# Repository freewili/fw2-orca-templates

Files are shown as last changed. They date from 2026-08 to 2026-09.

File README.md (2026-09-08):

# fw2-orca-templates

Example project templates for the FreeWili 2 ORCA module.

Currently supports:

- [KiCad](./kicad) — schematic/PCB template (`ORCATemplate`)
- [Connector pinouts](./PINOUTS.md) — Free Wili OG and Free Wili 2 20-position and 10-position connector pin tables
- [ORCA_NRF example](./examples/ORCA_NRF) — example ORCA module board carrying an NRF24L01 radio
- [GPIO Joiner example](./examples/gpiojoiner) — a routed KiCad 10 star board for testing a pair of FreeWili 2 / OG devices, with fabrication and assembly files

## KiCad template

The `kicad/` directory contains a starter KiCad 7 project (`ORCATemplate`) for
building ORCA module boards, including a 3D `.step` model and a custom
`EEPROM.pretty` footprint library.

The ORCA module connects via two headers, `CN1` and `CN2`:

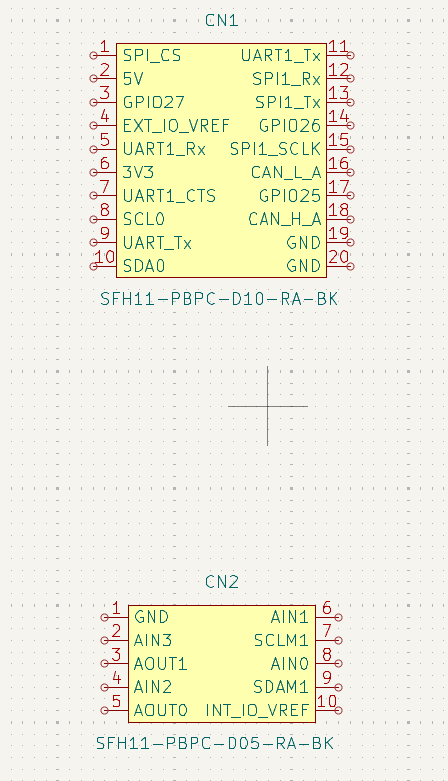
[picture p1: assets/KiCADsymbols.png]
ORCA connector symbols


> **Note:** `kicad/fp-lib-table` currently references footprint libraries
> (`IDC_10`, `IDC_20`) by absolute path on another machine. Update these
> library paths (or replace them with the project-relative `${KIPRJMOD}`
> style used for `EEPROM`) before relying on the template on a fresh
> checkout.

## ORCA_NRF example

The `examples/ORCA_NRF/` directory contains a complete example ORCA module
project built from the template: an NRF24L01 radio carrier with the `CN1`
(20-pin) and `CN2` (10-pin) headers and the ID EEPROM.

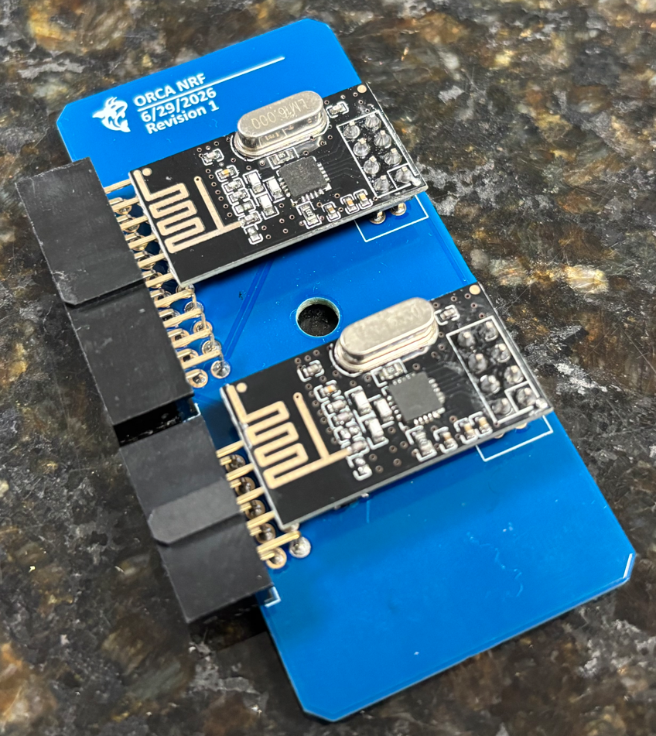
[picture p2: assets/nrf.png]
Assembled ORCA NRF example board with two NRF radio modules


User-provided photograph of the assembled ORCA NRF board.

> **Note:** The symbols and footprints are embedded in the schematic and PCB,
> so the project opens without extra libraries. The 3D model references in
> `ORCA_NRF.kicad_pcb` use absolute paths from another machine and will show
> as missing in the 3D viewer until you repoint them.

## GPIO Joiner example

[GPIO Joiner rev A](./examples/gpiojoiner) provides two opposing FreeWili 2
positions and two opposing OG positions. Connect one device per electrical
side, two devices total. A 24LC02BT ORCA EEPROM connects to shared FW2 I2C1.

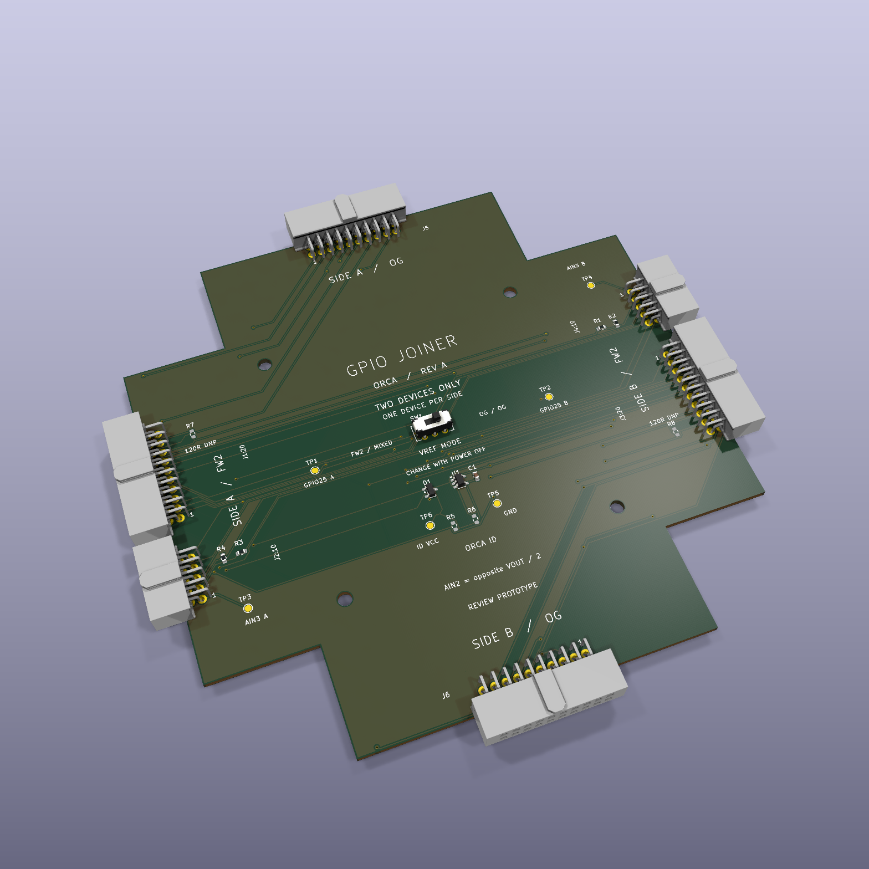
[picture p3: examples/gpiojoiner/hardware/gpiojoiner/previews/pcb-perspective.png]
GPIO Joiner rev A angled KiCad board preview


The example includes editable KiCad sources, project-local symbols,
footprints and 3D models, top/bottom board images, a schematic PDF, and
[prototype manufacturing files](./examples/gpiojoiner/hardware/gpiojoiner/manufacturing/revA).
The [PCBWay quote-form answers](./examples/gpiojoiner/hardware/gpiojoiner/manufacturing/PCBWAY-QUOTE-ANSWERS.md)
show how to request five fully assembled prototypes.

This is an unbuilt prototype: physical mating, EEPROM ID programming and
bench operation remain to be validated. Optional R5-R8 models appear in the
preview but are DNP in the assembly BOM. See the example README for operating
limits and verification evidence.

Repository agent workflow is documented in [AGENTS.md](./AGENTS.md).

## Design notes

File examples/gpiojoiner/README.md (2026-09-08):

# FreeWili GPIO Joiner

KiCad project for a four-arm star test board with FW2 connectors opposite
each other and OG connectors on the perpendicular axis. Rev A supports
**two connected devices, one on Side A and one on Side B**, using either
generation on each side.

GPIO Joiner rev A angled board preview

KiCad 3D preview of the routed prototype. Connector models show the board
layout; full device cases and physical mating have not been verified.
Optional R5-R8 models appear in these views but are DNP in the assembly BOM.

Open [gpiojoiner.kicad_pro](hardware/gpiojoiner/gpiojoiner.kicad_pro).
See the [board preview](hardware/gpiojoiner/previews/pcb-top.png),
[schematic PDF](hardware/gpiojoiner/previews/schematic.pdf), and
[setup instructions and BOM](hardware/gpiojoiner/README.md).

The required 24LC02BT ORCA EEPROM is connected to shared FW2 I2C1. VREF
mode is selected with a labeled switch. Programmable-output measurements
use 2:1 dividers, so test firmware must multiply the opposite AIN2 reading
by two. The original wiring authority remains [gpiojoiner spec.md](gpiojoiner%20spec.md).

Prototype manufacturing files for JLCPCB and PCBWay are prepared:
[Gerber ZIP](hardware/gpiojoiner/manufacturing/revA/gpiojoiner-revA-gerbers.zip),
[assembly package](hardware/gpiojoiner/manufacturing/revA/gpiojoiner-revA-assembly.zip),
and [order settings / fit check](hardware/gpiojoiner/manufacturing/revA/README.md).
The working quote is five fully assembled boards; no order has been placed.

This is a routed prototype. CAD verification is recorded in
[reports/verification.md](hardware/gpiojoiner/reports/verification.md).
Check actual device mating and supplier assembly previews before ordering.
EEPROM identification and bench validation remain required before production
release. Four simultaneously attached devices are unsupported by this revision.

| Top view | Bottom view |
| --- | --- |
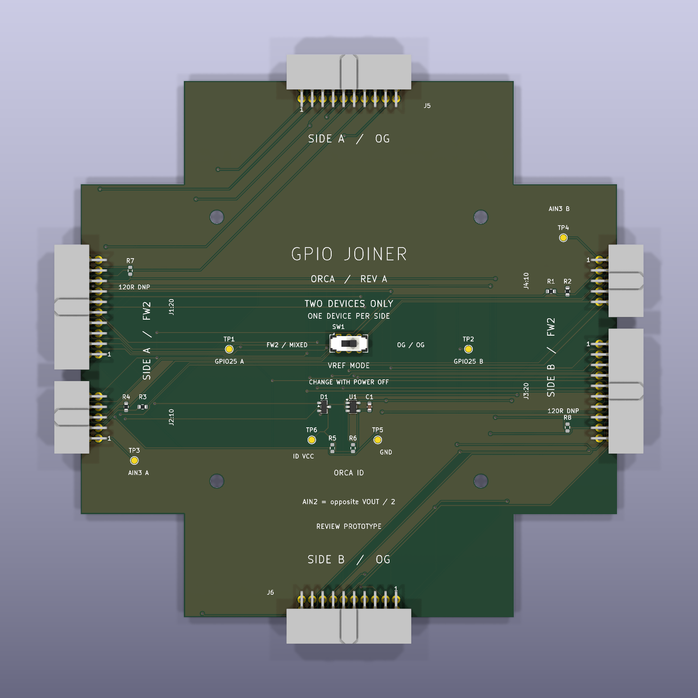
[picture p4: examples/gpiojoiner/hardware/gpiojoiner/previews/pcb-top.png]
Top of GPIO Joiner rev A
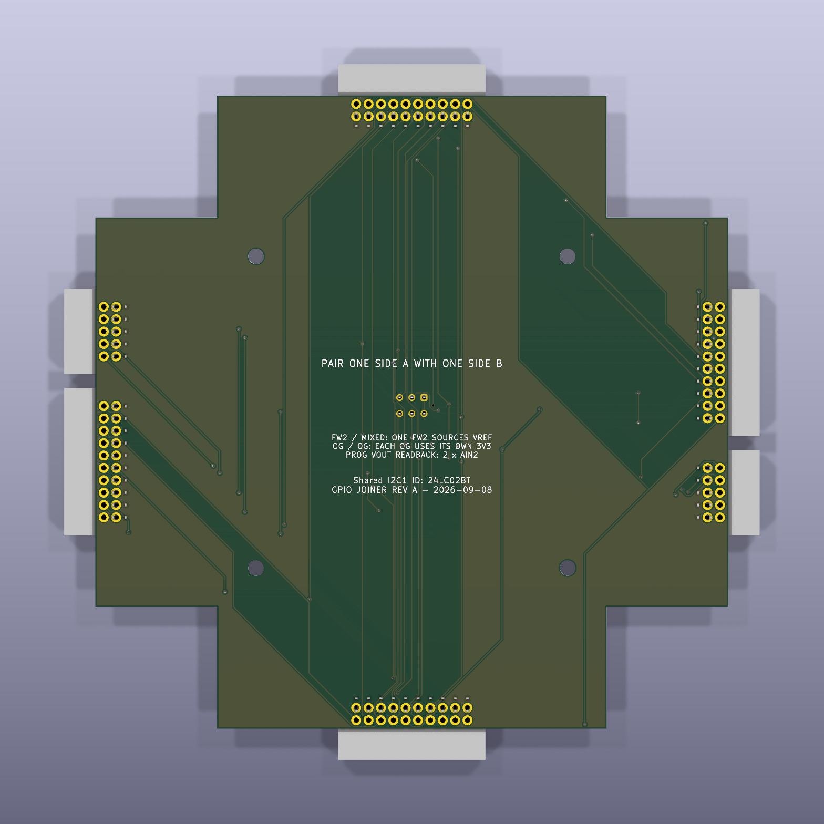
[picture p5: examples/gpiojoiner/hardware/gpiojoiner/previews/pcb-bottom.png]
Bottom of GPIO Joiner rev A
|  |  |

The [PCBWay quote-form answers](hardware/gpiojoiner/manufacturing/PCBWAY-QUOTE-ANSWERS.md)
provide a field-by-field example for requesting a fully assembled prototype.
Agent workflow and board requirements are recorded in [AGENTS.md](AGENTS.md).

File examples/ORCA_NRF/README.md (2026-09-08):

# ORCA NRF example

NRF radio carrier example for FreeWili 2.

Assembled ORCA NRF example board

Open [ORCA_NRF.kicad_pro](ORCA_NRF.kicad_pro) in KiCad to inspect the
[schematic](ORCA_NRF.kicad_sch) and [PCB](ORCA_NRF.kicad_pcb).

The photograph shows the assembled example board. The existing PCB's 3D
model references include absolute paths; see the [repository notes](../../README.md#orca_nrf-example)
when opening its 3D view on another machine.

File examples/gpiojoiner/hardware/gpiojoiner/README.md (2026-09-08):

# GPIO Joiner - rev A review prototype

Open **gpiojoiner.kicad_pro** in KiCad 10 or newer. The schematic, PCB,
symbol library, footprints, and 3D models are included in this folder.
See [schematic PDF](previews/schematic.pdf), [board preview](previews/pcb-top.png),
[design details](DESIGN.md), and [BOM](BOM.md).

[Prototype manufacturing package and order settings](manufacturing/revA/README.md)
are prepared for JLCPCB and PCBWay, including Gerbers, exact-part BOMs,
supplier placement CSVs, and a 1:1 fit/assembly PDF. The working quantity is
five fully assembled boards. No supplier order or live quote has been submitted.

Angled KiCad preview of GPIO Joiner rev A

| Top view | Bottom view |
| --- | --- |
| Top of the GPIO Joiner PCB | Bottom of the GPIO Joiner PCB |

These are CAD previews; full device enclosures and physical mating are not
verified. Optional R5-R8 models appear in the views but are DNP in the
prototype assembly BOM.

This revision implements the test cable described in the root
`gpiojoiner spec.md`. It has four docking positions in a star, intended
for **two attached devices: one on Side A and one on Side B**.

```text
                         OG A - J5
                            |
 FW2 A - J1 + J2 -------- JOINER -------- J3 + J4 - FW2 B
                            |
                         OG B - J6
```

| Test pair | Side A | Side B | SW1 position |
| --- | --- | --- | --- |
| FW2 / FW2 | West: J1 and J2 | East: J3 and J4 | FW2 / MIXED |
| OG / OG | North: J5 | South: J6 | OG / OG |
| FW2 / OG | West: J1 and J2 | South: J6 | FW2 / MIXED |
| OG / FW2 | North: J5 | East: J3 and J4 | FW2 / MIXED |

The two connector choices on a side share signals. Four simultaneously
attached devices, or two attached to the same side, are unsupported.
Supporting four attached devices would require added switching or isolation.

## Setup and tests

1. With both devices off, connect one device per side and set SW1.
2. In FW2 / MIXED mode, configure exactly one FW2 to supply VREF; the other
   device uses that external reference. In OG / OG mode, SW1 connects each
   OG's VREF to its own 3.3 V output. Change the switch with power off.
3. Power both devices before driving the shared interfaces. Configure GPIO
   directions and use one SPI clock/chip-select driver. UART/SPI data,
   UART flow control, and GPIO26/27 are crossed as specified.
4. For FW2 / FW2 analog tests, read AOUT0/1 on the other device's AIN0/1.
   Read programmable VOUT as **2 x the opposite AIN2 reading**. Two 10k/10k
   dividers accommodate the published 5.5 V programmable-output maximum.
   AIN3 and GPIO25 have labeled test pads only.

CAN connects only the two FW2 ports; OG SWD pins are unconnected. R7/R8 CAN
termination and R5/R6 I2C1 pull-ups are **DNP**. Check the devices' existing
termination and pull-ups before populating these optional resistors.

## ORCA identification

One **24LC02BT-E/OT** is permanently connected to the shared I2C1 bus on
both FW2 10-pin connectors (pin 7 SCL, pin 9 SDA). Its WP pin is grounded
for programming. A BAT54C diode OR powers it from either FW2's 3.3 V output
without directly joining those supply outputs.

Use a 3.3 V I2C1 bus, up to 400 kHz, with verified pull-ups. I2C1 voltage is
independent of the selected GPIO VREF. Reserve addresses **0x50 through
0x57**: this EEPROM ignores the three low address bits. Coordinate the two
hosts so only one controller accesses the bus at a time unless their
multi-controller behavior has been verified. The diode OR does not isolate
shared signal pins from an unpowered host.

The EEPROM hardware is included; a product-specific ORCA identification
image and a verified programming/boot procedure are still needed. No
identification contents or working auto-detection are claimed by this project.

## Physical and bench validation

The PCB is a 130 x 130 mm cross, two layers, 1.6 mm thick, with four 3.2 mm
mounting holes. FW2 20/10 connector centers are 26.72 mm apart, matching the
named starter template. The original example differs by 0.03 mm. Connector
centers are 3 mm inside the mating board edges. The included connector
models come from the template assembly; full device enclosures were not
available for clearance verification.

Before ordering the prototype, verify actual mating orientation, connector
gender/keying, spacing, board-to-case clearance, and support with real FW2
and OG devices. Check both SW1 contact states on the purchased part. The
project-local switch footprint corrects the installed library's reversed
second-row numbering using the manufacturer contact diagram.

Bench validation must also cover EEPROM supply voltage/read/write and
identification, both VREF modes, power sequencing, I2C pull-ups/ownership,
CAN termination, analog input loading/settling and divider calibration,
and the required test firmware for all four permitted pairs. Manufacturing
inputs are available for prototype quotation and engineering review; hardware
operation remains unverified and this is not a production release.

## Rechecking or regenerating

The editable KiCad files are the delivered design. For a full recheck,
run `tools/verify_project.py` with KiCad's bundled Python; it refreshes the
netlist, ERC/DRC, audits, and verification report. Alternatively, run the standard Python
`tools/check_connections.py` against a freshly exported KiCad XML netlist,
and run `tools/check_pcb.py` with KiCad's bundled Python (`pcbnew`). Also
run KiCad ERC and DRC with schematic parity enabled. Final reports belong
in `reports/`.

`generate_schematic.py` and `generate_pcb.py --rebuild` recreate the CAD
sources and **overwrite manual edits**. The PCB generator requires the
referenced template checkout and installed KiCad libraries. Rebuilding
removes routing. `route_pcb.py --java <java25> --jar <freerouting.jar>`
routes a board with no existing tracks and fills its ground pours.
`finish_routing.py` applies the local edge/thermal and label edits for the
delivered rev A routing; it is specific to those coordinates. A new router
run can produce different geometry and needs a fresh review and finishing
edits. Final KiCad DRC remains required. These development tools are optional for
opening and editing the delivered project.

Library origins and the source revision are recorded in [PROVENANCE.md](PROVENANCE.md).

Optional regeneration tools default to the Windows KiCad 10 install path.
Set `KICAD_INSTALL` for a different installation, and `KICAD_SYMBOL_DIR` when
the symbols are in a separate location. Verification accepts `--cli` for
the KiCad CLI path and needs Python with `pcbnew`. Opening the delivered
project does not require these development scripts or a template checkout.

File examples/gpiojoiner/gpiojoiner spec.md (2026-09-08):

i have a cable that connects two freewili devices. Its for automated testing of the FreeWili GPIO. Two FreeWili OG or Two FreeWili 2 or One OG connected to a FreeWili 2.

There is a 20 position connector and a 10 position connector. The twenty position is the same for Free Wili except the CANFD signals which are not present on FreeWili one.

To power the GPIO. the VREF is connected together. in this mode  one free wili2 would power both FreeWili devices. When two free wili ogs are connected VREF comes from 3.3V of each devices.

**20 Position Connector Info between two Wilis**

SPI is connected between the two with a rx and tx swap.

I2C is directly connected

UART is connects with rx/tx and cts/rts swap

CANFD is directly connected. (should be disconnected if either are OG)

GPIO26 is connected to GPIO 27

VREF is connected together OR if its two WILI OG it uses 3.3. The agent should make sure the user does this swap on the cable.

**10 Position Connector Info**

i2c is directly connected

analog output 0 is connected to analog input 0

analog output 1 is connected to analog input 1

prog vout is connected to analog input 2

analog input 3 is connected to xxx

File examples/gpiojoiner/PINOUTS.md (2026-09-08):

# Free Wili Connector Pinouts

This document lists the physical connector pin assignments for Free Wili OG and Free Wili 2. Directions are stated from the Free Wili device's perspective. GPIO pins are technically bidirectional; the direction shown is their default use.

In the source diagrams, even-numbered pins are on the upper row and odd-numbered pins are on the lower row. The 20-position connector notch is between positions 10 and 12 when viewed in the depicted orientation.

## Free Wili OG - 20-position connector

[Source connector image](assets/freewiliOGconnector.jpg)

| Pin | Signal | GPIO / Notes | Default direction |
| ---:| --- | --- | --- |
| 1 | SPI1_CS_OUT | GPIO13 | Output |
| 2 | 5V OUT | - | Power output |
| 3 | GPIO_27_OUT | GPIO27 | Output |
| 4 | V PINS IN | - | Power input |
| 5 | UART1_Rx_IN | GPIO9 | Input |
| 6 | 3.3V OUT | - | Power output |
| 7 | UART1_CTS_IN  | GPIO10 | Input |
| 8 | I2C 0 SCL | GPIO17 | Bidirectional |
| 9 | UART1_Tx_OUT  | GPIO8 | Output |
| 10  | I2C 0 SDA | GPIO16 | Bidirectional |
| 11  | UART1_RTS_OUT | GPIO11 | Output |
| 12  | SPI1_Rx_IN | GPIO12 | Input |
| 13  | SPI1_Tx_OUT | GPIO15 | Output |
| 14  | GPIO26_IN | GPIO26 | Input |
| 15  | SPI1_SCLK_OUT | GPIO14 | Output |
| 16  | SWCLK IN | SWCLK | Input |
| 17  | GPIO25_OUT | GPIO25 | Output |
| 18  | SWDIO | SWDIO | Bidirectional |
| 19  | GND | - | Ground |
| 20  | GND | - | Ground |

## Free Wili 2 - 20-position connector

[Source connector image](assets/freewili2connector.png)

| Pin | Signal | GPIO / Notes | Default direction | Breakout color |
| ---:| --- | --- | --- | --- |
| 1 | SPI1_CS_OUT | GPIO13 | Output | Green |
| 2 | 5V OUT | - | Power output | Red |
| 3 | GPIO_27_OUT | GPIO27 | Output | Yellow |
| 4 | TRIG IN/VREF  | - | Input | Gray |
| 5 | UART1_Rx_IN | GPIO9 | Input | Purple |
| 6 | 3.3V OUT | - | Power output | Red |
| 7 | UART1_CTS_IN  | GPIO10 | Input | Purple |
| 8 | I2C 0 SCL | GPIO17 | Bidirectional | Blue |
| 9 | UART1_Tx_OUT  | GPIO8 | Output | Purple |
| 10  | I2C 0 SDA | GPIO16 | Bidirectional | Blue |
| 11  | UART1_RTS_OUT | GPIO11 | Output | Purple |
| 12  | SPI1_Rx_IN | GPIO12 | Input | Green |
| 13  | SPI1_Tx_OUT | GPIO15 | Output | Green |
| 14  | GPIO26_IN_BI  | GPIO26 | Input | Yellow |
| 15  | SPI1_SCLK_OUT | GPIO14 | Output | Green |
| 16  | CANFD L | - | Bidirectional | Orange |
| 17  | GPIO25_OUT | GPIO25 | Output | Yellow |
| 18  | CANFD H | - | Bidirectional | Orange |
| 19  | GND | - | Ground | Black |
| 20  | GND | - | Ground | Black |

## Free Wili 2 - 10-position connector

[Source connector image](assets/freewili2connector.png)

| Pin | Signal | GPIO / Notes | Default direction | Breakout color |
| ---:| --- | --- | --- | --- |
| 1 | GND | - | Ground | Black |
| 2 | AIN3 | - | Input | White |
| 3 | AOUT1 | - | Output | Orange |
| 4 | AIN2 | - | Input | White |
| 5 | AOUT0 | - | Output | Orange |
| 6 | AIN1 | - | Input | White |
| 7 | I2C 1 SCL | - | Bidirectional | Blue |
| 8 | AIN0 | - | Input | White |
| 9 | I2C 1 SDA | - | Bidirectional | Blue |
| 10  | PROG VOUT | - | Output | Red |

## 20-position connector comparison

| Pin | Free Wili OG  | OG default direction | Free Wili 2 | Free Wili 2 default direction | Difference |
| ---:| --- | --- | --- | --- | --- |
| 1 | SPI1_CS_OUT | Output | SPI1_CS_OUT | Output | Same |
| 2 | 5V OUT | Power output | 5V OUT | Power output | Same |
| 3 | GPIO_27_OUT | Output | GPIO_27_OUT | Output | Same |
| 4 | VREF | Power input | TRIG IN/VREF  | Input | VREF -> TRIG IN/VREF (freewili 2 support VREF Output) |
| 5 | UART1_Rx_IN | Input | UART1_Rx_IN | Input | Same |
| 6 | 3.3V OUT | Power output | 3.3V OUT | Power output | Same |
| 7 | UART1_CTS_IN  | Input | UART1_CTS_IN  | Input | Same |
| 8 | I2C 0 SCL | Bidirectional | I2C 0 SCL | Bidirectional | Same |
| 9 | UART1_Tx_OUT  | Output | UART1_Tx_OUT  | Output | Same |
| 10  | I2C 0 SDA | Bidirectional | I2C 0 SDA | Bidirectional | Same |
| 11  | UART1_RTS_OUT | Output | UART1_RTS_OUT | Output | Same |
| 12  | SPI1_Rx_IN | Input | SPI1_Rx_IN | Input | Same |
| 13  | SPI1_Tx_OUT | Output | SPI1_Tx_OUT | Output | Same |
| 14  | GPIO26_IN_BI  | Input | GPIO26_IN_BI  | Input | Same |
| 15  | SPI1_SCLK_OUT | Output | SPI1_SCLK_OUT | Output | Same |
| 16  | SWCLK IN | Input | CANFD L | Bidirectional | SWCLK IN -> CANFD L |
| 17  | GPIO25_OUT | Output | GPIO25_OUT | Output | Same |
| 18  | SWDIO | Bidirectional | CANFD H | Bidirectional | SWDIO -> CANFD H |
| 19  | GND | Ground | GND | Ground | Same |
| 20  | GND | Ground | GND | Ground | Same |

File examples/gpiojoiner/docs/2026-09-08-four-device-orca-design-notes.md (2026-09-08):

# Four-position ORCA GPIO joiner: initial reference audit

**Superseded by the rev A KiCad prototype:** the user clarified that
generally two devices are connected. The implemented board uses one
device on Side A (west FW2 or north OG) and one on Side B (east FW2 or
south OG). See [current design](../hardware/gpiojoiner/DESIGN.md),
[setup instructions](../hardware/gpiojoiner/README.md), and the updated
[pair connection matrix](pair-connection-matrix.md).

The historical notes below record the initial reference audit before the
schematic and PCB were created. Their open choices have since been resolved
in DESIGN.md, except physical mating and the explicitly listed bench tests.

## Requested physical arrangement

One PCB directly mates with up to two FreeWili 2 and two FreeWili OG devices.
Each generation occupies opposite arms of a four-arm star. Conceptual top
view, with devices extending outward from the PCB:

```text
                       FreeWili OG A
                            |
                         20-pin
                            |
 FreeWili 2 A -- 20+10 -- JOINER -- 20+10 -- FreeWili 2 B
                            |
                         20-pin
                            |
                       FreeWili OG B
```

The lines show physical placement, not common electrical nets. This means
four 20-position mating connectors and two 10-position mating connectors.
Connector gender, key orientation, exact part numbers, enclosure clearance,
and mechanical support must be verified before fixing the board dimensions.

## Reference inspection

Inspected upstream commit `f8f26dfa2b6454a27f454f303fe2a669ac94eca2` from
[fw2-orca-templates](https://github.com/freewili/fw2-orca-templates).
Local KiCad CLI version: 10.0.6. Both upstream schematics exported to XML
netlists successfully, and both PCB files loaded through KiCad's Python API.
These are reference readability checks, not electrical or layout approval.

- `kicad/ORCATemplate.kicad_sch` instantiates only CN1 and CN2. The EEPROM
  footprint is supplied separately; the starter does not already contain
  the mandatory EEPROM circuit.
- `examples/ORCA_NRF/ORCA_NRF.kicad_sch` contains a wired EEPROM. Its exported
  netlist confirms the four signal/power connections in the table below.
- Connector footprints are embedded in the reference PCB files. The starter
  footprint table uses unavailable absolute library paths and duplicate
  entries; the project must use self-contained, project-relative libraries.
- Reference 3D model paths also point to another machine. The available
  ORCATemplate STEP file must be inspected before assuming it provides the
  complete device/enclosure mating geometry.
- The starter's 20-pin and 10-pin footprint centers are 26.72 mm apart; the
  NRF example uses 26.69 mm. Their pitch is 2.54 mm with 1.1 mm drills.
  These measured file values need a mechanical source of truth; do not
  silently choose between the differing center spacings.

## Mandatory identification EEPROM

The user requires a 24LC02BT on I2C1 of the 10-position connector, and the
user-designated wiring specification requires direct I2C1 connection
between the FW2 devices. Proposed implementation: one 24LC02BT-E/OT on
that shared bus. The supply circuit must allow the supported device
combinations without paralleling the two hosts' 3.3 V outputs.

| EEPROM SOT-23 pin | Function | Proposed connection |
| --- | --- | --- |
| 1 | SCL | Shared FW2 10-position pin 7, I2C1 SCL |
| 2 | VSS | GND, including 10-position pin 1 and 20-position pins 19/20 |
| 3 | SDA | Shared FW2 10-position pin 9, I2C1 SDA |
| 4 | VCC | Board EEPROM supply; source selection circuit to be designed |
| 5 | WP | Defined logic level; proposed GND for EEPROM programming |

The example labels pin 5 as NC and leaves it unconnected. Microchip's
DS20001709L Table 2-1 specifies WP on SOT-23 pin 5, and section 2.4 requires
WP to be tied to VSS or VCC. Correct the reused symbol and connection.
Provide local supply decoupling and establish the actual host I2C1 pull-up
voltage/resistance before selecting additional pull-ups.

Section 5.0 of the datasheet specifies three ignored address bits. These
EEPROMs therefore respond to the same address range (0x50-0x57); assigning
different software addresses cannot separate two parts on one bus. Use
one shared EEPROM for the proposed shared-bus design. Define host bus
ownership, pull-up supply, and unpowered-host behavior. The earlier
separate-bus recommendation is superseded by the user's wiring specification.

The EEPROM identification data format and programming procedure also need
to be established before claiming ORCA auto-detection works.

Source: [Microchip 24AA02/24LC02B/24FC02 datasheet, sections 2 and 5](https://ww1.microchip.com/downloads/en/DeviceDoc/24AA02-24LC02B-24FC02-Data-Sheet-20001709L.pdf).

## Electrical topology decision

The user-designated `gpiojoiner spec.md` defines two-device GPIO testing, including
UART and SPI RX/TX swaps, UART flow-control swaps, GPIO26/GPIO27 pairing,
and generation-dependent VREF handling. It does not define four-device
routing. Its signal wiring is captured in the
[pair connection matrix](pair-connection-matrix.md). Possible applications
of that established pair wiring to four physical ports are:

1. Select any two connected devices as test partners. This retains mixed
   FW2/OG testing. Manual selection or an active switch network would need
   its own design decision.
2. Run two fixed pairs, FW2-to-FW2 and OG-to-OG. This is the simplest passive
   routing but does not provide mixed-generation testing.
3. Have all four communicate together. This needs a protocol-specific
   arrangement and output ownership, rather than treating every signal
   as a shared four-device bus.

The initial recommendation for the existing test-cable use case is option
1, subject to the user's intended test workflow. No option is selected yet.

## Constraints on the eventual circuit

- Keep independent 5 V, 3.3 V, and programmable supply outputs from being
  directly paralleled. A VREF source/selection scheme must follow the
  selected pair and the device configurations.
- FW2 20-position pin 16 is CAN L and pin 18 is CAN H in the project's
  connector drawings and upstream example. The corresponding OG pins are
  SWCLK and SWDIO. Keep CAN routing exclusive to the FW2 ports.
- Configure signal directions before testing. UART TX, RTS, GPIO outputs,
  and SPI clock/chip-select drivers cannot be blindly joined across hosts.
  Confirm the original SPI RX/TX swap against the intended firmware test
  modes before adopting it as schematic wiring.
- The existing cable notes request analog output-to-input and programmable
  output-to-input tests. Verify voltage limits and necessary scaling before
  connecting PROG VOUT to an analog input. AIN3 and GPIO25 test coverage
  remain to be defined.
- Correct inherited symbol naming: 20-position pin 11 is UART RTS even
  though the example calls it UART1_Tx; 10-position pin 10 is PROG VOUT in
  the project pinout but INT_IO_VREF in the example symbol.
- Establish ground and return paths, including the FW2 CAN interface's
  isolation/grounding and termination requirements, from the device hardware.

Project pin assignments: [PINOUTS.md](../PINOUTS.md).
Additional context: [FreeWili pinout documentation](https://docs.freewili.com/hardware/pinout/)
and [ORCA module documentation](https://docs.freewili.com/hardware/orca-modules/).

## Verification before fabrication

The eventual KiCad project needs a checked connection matrix, schematic
ERC, PCB DRC, schematic/PCB consistency checks, connector mating and
enclosure clearance verification, and reviewed manufacturing outputs.
Bench validation must cover each supported populated-device combination,
power sequencing, ORCA identification, and the selected GPIO/bus tests.
No such fabrication or hardware validation is claimed by this audit.

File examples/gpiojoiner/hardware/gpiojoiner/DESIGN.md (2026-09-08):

# GPIO Joiner rev A

## Scope and operating arrangement

Build a KiCad schematic and PCB for the user's passive two-device GPIO test
cable, with four physical docking positions. User clarification: generally
only two devices are connected. Use one device on Side A and one on Side B.
West FW2 and north OG are Side A; east FW2 and south OG are Side B. Both
FW2 and both OG devices are opposite their own generation. The two mixed
pairs are west FW2/south OG and north OG/east FW2. Four attached devices,
or two on the same side, are not supported in this passive revision.

The user's `gpiojoiner spec.md` is the wiring authority. The root
`PINOUTS.md` supplies physical pin numbers. Reference connector geometry
comes from freewili/fw2-orca-templates commit
f8f26dfa2b6454a27f454f303fe2a669ac94eca2.

## Circuit

- J1: FW2 A 20-pin; J2: FW2 A 10-pin; J3: FW2 B 20-pin;
  J4: FW2 B 10-pin; J5: OG A 20-pin; J6: OG B 20-pin.
- Side A J1/J5 share GPIO interface signals, with individual 3.3 V outputs.
  Side B J3/J6 likewise. 5 V outputs are unconnected. OG SWD pins 16/18
  are unconnected. FW2 CAN L/H join only J1 and J3 pins 16/18.
- Cross between sides: SPI 13/12, UART 9/5 and 11/7, GPIO 3/14.
  SPI CS 1/1, clock 15/15, I2C0 8/8 and 10/10 are straight-through.
  GPIO25 pin 17 is brought to one test point per side, not cross-connected.
- All paired digital/analog grounds are common.
- A DPDT VREF mode switch SW1 has commons 2=VREF_A and 5=VREF_B.
  Throws 1 and 4 share a link net (FW2/mixed mode); throw 3 connects only
  OG A 3.3 V and throw 6 only OG B 3.3 V (OG/OG mode).
  Part: C&K JS202011CQN with corrected project-local THT footprint
  GPIOJoiner:SW_JS202011CQN. Pins 4/6 are exchanged from the installed
  library footprint so 4 is opposite 1 and 6 opposite 3, following the
  manufacturer's contact diagram. Verify continuity before assembly release.
  Change mode with both devices off. FW2/mixed uses exactly one FW2 IO
  voltage source; OG/OG gives each side its own local 3.3 V reference.
- J2/J4 I2C1 pins 7 and 9 connect directly as requested.
  U1 is one shared 24LC02BT-E/OT: 1=SCL, 2=GND, 3=SDA, 4=VCC, 5=WP.
  WP is tied to GND so the EEPROM can be programmed. Two independent FW2
  3.3 V outputs feed BAT54C common-cathode D1 pins 1/2; pin 3 supplies U1.
  C1=100 nF decouples U1. R5/R6=4.7k I2C1 pull-ups are DNP pending host
  pull-up measurement. Never fit two unisolated 24LC02B parts to this bus.
- Analog connections in both directions: AOUT0 pin 5 to opposite AIN0 pin 8;
  AOUT1 pin 3 to opposite AIN1 pin 6.
- PROG VOUT can reach 5.5 V while the published ADC range is 0–5 V. Use
  a 10k/10k divider for each PROG VOUT to opposite AIN2 pin 4 path:
  R1/R2 for A-to-B and R3/R4 for B-to-A. Firmware recovers VOUT as
  twice the AIN2 reading. Use 0.1% resistors, 0603 footprints.
- AIN3 pin 2 has a test point per FW2; the source says `xxx`, so no
  stimulus is invented. No automatic CAN termination is fitted; provide
  DNP 120-ohm termination footprints R7/R8 near each FW2 connector,
  populated only after checking the devices' existing termination.

## Mechanical draft

Use the template's embedded 20-pin/10-pin right-angle connector footprints
with project-local libraries. Preserve 2.54 mm pitch and template FW2
connector-center separation 26.72 mm. The NRF example differs by 0.03 mm;
use the named starter template consistently and flag mating verification.

Initial outline: a 130 x 130 mm four-arm cross, 80 mm wide arms, two copper
layers, 1.6 mm thickness. Four 3.2 mm support holes in the central area.
Connector centers are 3 mm inside their mating board edges. Route with
0.20 mm tracks, 0.15 mm copper clearance, and 0.30 mm copper-edge clearance;
this permits signal escape through the template's 0.508 mm pad gaps.
Place connector mating faces outward. Clearly mark side, generation,
pin 1, mode switch positions, and ONE DEVICE PER SIDE / TWO DEVICES ONLY.
Connector body and device-case clearance need physical mating validation;
the template STEP model is not a verified complete FW2 or OG enclosure.

## Deliverables and verification

Create project-local symbols/footprints, editable schematic and routed PCB,
BOM, schematic PDF/SVG and board previews, connection audit and ERC/DRC
reports. At the user's request, provide prototype manufacturing/assembly
inputs for JLCPCB and PCBWay with exact part numbers, fit drawings and
independent CAM checks. These are quotation and prototype-order inputs;
they do not establish production readiness. Verify physical mating before
ordering. Validate pull-ups, CAN termination, EEPROM identification contents,
and firmware operation on the prototypes before production release.

Manufacturing presentation uses at least 1.0 mm silkscreen text height and
0.15 mm strokes. Plot/drill/assembly datum is the lower-left board bounding
box corner, KiCad (85, 215) mm. Order specification: 1 oz copper, ENIG,
green mask and white legend. Solder-paste output omits DNP R5-R8 apertures.

Verify every specified A/B pin connection on exported KiCad netlists,
including all four permitted combinations, supply isolation, both switch
modes, EEPROM pins, and analog divider topology. Check PCB/schematic pad
net agreement, ERC, DRC, and visually inspect schematic and PCB exports.

## Sources

- https://github.com/freewili/fw2-orca-templates
- https://ww1.microchip.com/downloads/en/DeviceDoc/24AA02-24LC02B-24FC02-Data-Sheet-20001709L.pdf
- https://assets.nexperia.com/documents/data-sheet/BAT54C.pdf
- https://freewili.com/specs/programmable-power.html
- https://docs.freewili.com/hardware/pinout/

The divider, manual VREF switch, spare-pin test points, DNP pull-ups and
termination pads are design choices made to implement the source safely
and keep the first board useful for validation.

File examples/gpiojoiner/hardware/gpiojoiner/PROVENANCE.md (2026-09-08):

# CAD source provenance

- Wiring authority: user-provided `gpiojoiner spec.md` in the repository root.
  Physical pin assignments: root `PINOUTS.md`. Design decisions beyond the
  cable notes are identified in [DESIGN.md](DESIGN.md).
- ORCA reference: [freewili/fw2-orca-templates](https://github.com/freewili/fw2-orca-templates),
  commit `f8f26dfa2b6454a27f454f303fe2a669ac94eca2`.
  The two `GPIOJoiner:ORCA_*_RA` footprints derive from the embedded
  connectors in `kicad/ORCATemplate.kicad_pcb`. Pad coordinates, sizes,
  numbering, and drills are preserved. Courtyards, corrected through-hole
  attributes, and local model references were added; original corner marks
  were moved to the fabrication layer.
- `models/ORCA_20_RA.step` and `ORCA_10_RA.step` are connector solids extracted
  from `kicad/ORCATemplate.step` and translated to footprint coordinates.
  They describe connectors, not complete FreeWili enclosures. The upstream
  checkout did not contain a separate license file; no new upstream license
  is asserted here.
- Other footprints and their STEP models originate from the installed
  KiCad 10 library distribution. KiCad library assets use CC BY-SA 4.0
  with the KiCad design exception; see the [KiCad library license](https://www.kicad.org/libraries/license/).
  Symbols in `GPIOJoiner.kicad_sym` were authored for this project using
  the interface pin assignments and manufacturer component pinouts.
- `GPIOJoiner:SW_JS202011CQN` derives from KiCad's
  `Button_Switch_THT:SW_CK_JS202011CQN_DPDT_Straight`, with pad numbers
  4 and 6 exchanged to make rows 1/2/3 and 4/5/6 parallel. This follows
  the manufacturer's contact diagram, reviewed in
  [circuit-review.md](reports/circuit-review.md). Verify on the physical part.

KiCad 10.0.6 exported the schematic netlist, ERC, DRC, and previews.
Freerouting 2.2.4 / Java 25 performed local routing; no remote routing
service was used. Routing inputs and its log are retained under
`reports/routing/`; final KiCad DRC, not the router's score, establishes
the reported CAD connectivity and clearance result.

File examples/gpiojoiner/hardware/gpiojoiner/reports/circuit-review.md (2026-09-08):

# Independent circuit review — 2026-09-08

Scope: DESIGN.md, source wiring specification, PINOUTS.md, exported KiCad
netlist, generated PCB and generators, and manufacturer documentation.
Mechanical mating and firmware/bench behavior remain outside CAD verification.

## Important finding: switch footprint numbering

C&K's JS-series datasheet (22 Sep 2022), page 4 / I-53, explicitly shows
JS202011CQN state b closing **1–2 and 4–5**; the other state closes
**2–3 and 5–6**. DESIGN.md uses these correct manufacturer contact pairs.
The installed KiCad footprint instead places row 6/5/4 opposite row
1/2/3. Reusing that numbering would select opposite throws between poles.
Use the project-local corrected footprint, with 4 opposite 1 and 6 opposite
3. Keep the schematic and contact simulation in manufacturer numbering.
The final project-local footprint and placed board now have this correction:
terminals 1/4 share x=147.5 mm, terminals 3/6 share x=152.5 mm, and commons
2/5 share x=150 mm. Correct throw/common nets were independently inspected.
Confirm both states by continuity on a physical switch before assembly
release. The datasheet mechanically marks terminal 1 only.

Source: [C&K manufacturer datasheet, distributor mirror](https://datasheet.lcsc.com/datasheet/pdf/418f5deccdcf85a20b545dc49037ad89.pdf?productCode=C221657).
The review visually inspected the rendered page, not just extracted text.

## Findings and operating conditions

- **Port mapping passes.** The four allowed A/B pairings implement the
  prescribed SPI/UART/GPIO crosses, straight I2C0, and FW2-only CAN.
  OG SWD remains disconnected. One device per side is essential because
  alternative docking positions share signal copper.
- **VREF topology is correct once the footprint is corrected.** Linked
  mode requires exactly one FW2 voltage source and the other device in
  external-reference mode. OG/OG mode keeps the two 3.3 V outputs separate.
  Power off before changing the mode or connecting devices.
- **EEPROM pinout and supply polarity pass.** SOT-23 pins are
  1=SCL, 2=GND, 3=SDA, 4=VCC, 5=WP. BAT54C pins 1/2 are anodes and pin 3
  is the shared cathode. Its voltage drop leaves reasonable nominal
  headroom from 3.3 V above the EEPROM's 2.5 V minimum; measure VCC during
  reads and writes from either FW2 alone. Diode OR prevents a direct
  supply-output short but does not isolate shared signal pins.
- **Document I2C1 operating limits.** Use at most 400 kHz. The EEPROM
  responds at every address 0x50–0x57, so reserve the entire range. Verify
  3.3 V bus levels independently of selectable VREF: EEPROM absolute
  maximum input voltage is VCC+1 V. Coordinate the two controllers during
  identification; simultaneous independent boot scans need firmware
  arbitration or sequencing. DNP pull-ups are reasonable for this review
  prototype, but fit/enable verified pull-ups before expecting operation.
- **Analog topology passes with a calibration condition.** Each 10k/10k
  divider gives 2.75 V nominal at 5.5 V PROG VOUT, approximately 5 kohm
  source impedance and 0.275 mA load. Firmware must apply the documented
  factor of two. Verify ADC loading/settling and gain with a known voltage;
  the published interface data does not establish input impedance here.
  AOUT0/1 cross to opposite AIN0/1. AIN3 stays unspecified/test-point only.
- **Firmware directions remain part of safe operation.** Straight SPI
  CS/clock require only one output driver. Both attached hosts should be
  powered before driving the shared interfaces; partial-power behavior
  has not been established. Existing CAN termination and I2C pull-ups
  must be measured as already required by DESIGN.md.

Sources: [Microchip 24LC02B](https://ww1.microchip.com/downloads/en/DeviceDoc/24AA02-24LC02B-24FC02-Data-Sheet-20001709L.pdf),
[Nexperia BAT54C](https://assets.nexperia.com/documents/data-sheet/BAT54C.pdf),
[FreeWili pinout and analog ranges](https://docs.freewili.com/hardware/pinout/),
[FreeWili programmable power](https://freewili.com/specs/programmable-power.html).

## Final CAD review checks

- `python hardware/gpiojoiner/tools/check_connections.py` passed
  **216 assertions**, four pairings, both modeled switch states and
  37 exact copper-net groups.
- KiCad Python `check_pcb.py` passed **138 schematic pad/net assignments**,
  connector spacing/orientation, corrected switch, DNPs, holes and local models.
- Independently compared both local ORCA footprint pad coordinates, sizes
  and drills against normalized upstream template footprints: exact matches.
  FW2 connectors are rotated together and remain 26.72 mm apart. Mating
  faces point west/east for FW2 and north/south for OG, based on the
  template body orientation. These comparisons cannot establish enclosure fit.
- Independently inspected placed D1 and U1 pad/net assignments: correct.
- Existing strict ERC report contains zero violations.

## Final routing and documentation review

The final `drc.json`, dated 2026-09-08 17:24:24, reports **zero violations,
zero unconnected items, and zero schematic-parity discrepancies**. Its
configured ignored checks are listed in that JSON; electrical connectivity
and copper-clearance checks are enabled. Earlier incomplete routing,
edge-clearance errors and thermal issues are resolved, not accepted exceptions.

The board contains 509 track segments at 0.20 mm width and 52 vias. Its
configured minimum copper clearance is 0.15 mm and copper-edge clearance
is 0.30 mm. This agrees with DESIGN.md and allows escape through the
source connector footprints' 0.508 mm pad gaps. Ground is routed explicitly
and has filled zones on both copper layers. Local endpoint, jog and thermal
adjustments are recorded in `tools/finish_routing.py`.

Fresh final-board checks again passed 216 schematic assertions and 138
PCB pad/net assignments. README.md, BOM.md, DESIGN.md and PROVENANCE.md
agree on the four pairings, VREF modes, shared EEPROM, divider calibration,
optional DNP parts and prototype limitations. BOM totals are correct:
14 normally populated parts, four optional resistors, six copper test pads
and four mechanical holes. Connector part numbers match the named upstream
starter; that verifies provenance rather than physical mating.

The board preview was visually inspected. A reversed apparent order in
combined connector labels was identified and corrected: each J1/J2/J3/J4
label now has the corresponding connector-center y coordinate in the CAD.
Regeneration remains a development workflow requiring fresh DRC; its
coordinate-specific finishing helper is not a general routing repair tool.

**Assessment:** no outstanding substantive electrical/CAD findings for
this review prototype. The physical mating, switch continuity and firmware/
bench conditions above remain required before manufacturing release.

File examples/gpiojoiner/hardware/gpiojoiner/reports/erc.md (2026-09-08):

# Schematic verification — rev A prototype

Verified with KiCad CLI 10.0.6 on 2026-09-08.

- `sch erc --exit-code-violations`: **0 violations**, exit 0.
  Machine-readable results are in `erc.json`; readable results are in `erc.rpt`.
- `python tools/check_connections.py`: **216 assertions passed** against the
  KiCad-exported `netlist.xml`, covering four permitted device pairs, both
  VREF switch modes, 37 exact connected-net memberships, all 24 physical
  components and footprints, EEPROM pins, supply/CAN isolation, both analog
  divider paths, and required DNP parts. Eight no-connect connector pins are
  also checked for isolation.
- The audit was written before the schematic and initially failed with the
  expected missing-netlist message. Independent mutation checks rejected a
  reversed diode connection, missing UART crossing, wrong divider resistance,
  wrong switch footprint, and populated CAN termination.
- The local symbol library independently loaded and exported all 10 symbols.
- The A3 PDF, SVG, and raster preview were exported and visually inspected;
  connector assignments, notes, divider topology, EEPROM, mode switch, and
  DNP/test-point groups are readable without overlapping labels.

The manufacturer JS202011CQN contact states are 1–2/4–5 and 2–3/5–6.
The schematic uses the corrected project-local `GPIOJoiner:SW_JS202011CQN`
footprint. The parent PCB task verified its parallel terminal-row numbering;
the installed generic footprint's serpentine second-row numbering was not
reused. Link throws are 1/4, common VREF terminals 2/5, and OG supply throws 3/6.

The schematic contains two non-board power flags for ERC and 24 board
components/etched pads. TP1 through TP6 are excluded from the purchasing BOM
and remain on the board, matching their standard copper-pad footprints.
The other 18 components retain their BOM inclusion (four resistors are DNP).
The PCB adds its mechanical mounting holes separately.

After this BOM parity adjustment, the schematic was regenerated and comparison
confirmed exactly six `in_bom` changes with every exported net membership
unchanged. The 216-assertion connection audit and strict ERC both passed again;
PDF/SVG/PNG previews and both ERC reports were refreshed.

These results verify the CAD circuit. Physical mating, I2C pull-ups, existing
CAN termination, EEPROM identification contents, and firmware operation still
require the bench validation described in `../DESIGN.md` before release.

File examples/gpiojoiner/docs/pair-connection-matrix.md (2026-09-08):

# GPIO joiner pair connection matrix

Derived from the user-designated wiring specification,
[`gpiojoiner spec.md`](../gpiojoiner%20spec.md), and the physical pin assignments
in [`PINOUTS.md`](../PINOUTS.md).

A and B identify the two devices taking part in a test. Rev A assigns
west FW2 (J1/J2) and north OG (J5) to Side A, and east FW2 (J3/J4) and
south OG (J6) to Side B. Use only one device on each side.
All arrows below represent physical connections; the signal names describe
the intended test direction. GPIO and SPI directions must be configured
for the chosen test before enabling their output drivers.

## 20-position connectors

| Function | Device A pin | Device B pin | Requirement |
| --- | ---: | ---: | --- |
| SPI A TX to B RX | 13 | 12 | RX/TX swap specified by user |
| SPI B TX to A RX | 12 | 13 | RX/TX swap specified by user |
| SPI chip select | 1 | 1 | Straight-through interpretation of SPI connection |
| SPI clock | 15 | 15 | Straight-through interpretation of SPI connection |
| UART A TX to B RX | 9 | 5 | RX/TX swap |
| UART B TX to A RX | 5 | 9 | RX/TX swap |
| UART A RTS to B CTS | 11 | 7 | RTS/CTS swap |
| UART B RTS to A CTS | 7 | 11 | RTS/CTS swap |
| I2C0 SCL | 8 | 8 | Direct connection |
| I2C0 SDA | 10 | 10 | Direct connection |
| GPIO27 A to GPIO26 B | 3 | 14 | GPIO26/GPIO27 pairing |
| GPIO27 B to GPIO26 A | 14 | 3 | Reciprocal interpretation of pairing |
| CAN L | 16 | 16 | FW2-to-FW2 only; disconnected for OG or mixed pairs |
| CAN H | 18 | 18 | FW2-to-FW2 only; disconnected for OG or mixed pairs |
| VREF | 4 | 4 | Connected for a pair containing FW2; one FW2 supplies IO voltage |
| Ground | 19, 20 | 19, 20 | Common return for the paired GPIO interfaces |
| 5 V outputs | 2 | 2 | No direct A-to-B connection specified; keep separate |
| 3.3 V outputs | 6 | 6 | Keep supplies separate; local use for OG VREF and EEPROM power |
| GPIO25 | 17 | 17 | No test connection specified |

SPI clock/chip select sharing requires compatible drive modes. The user
explicitly specifies crossed SPI data; this table preserves that test
wiring. It must not be silently changed to conventional peripheral wiring.

### VREF configuration

- **FW2/FW2 or FW2/OG:** connect pin 4 between the selected devices. Configure
  one FW2 as the IO-voltage source and the other device to use that reference.
- **OG/OG:** disconnect the pin-4 link and connect each OG's pin 4 to its own
  pin 6 (3.3 V), following the specification's local-supply instruction.
  This avoids paralleling the two 3.3 V outputs through VREF.
- Provide a clearly labeled board selection mechanism for these modes.
  The spec explicitly requires checking this change when switching device
  combinations. Source choice and signal connectivity must agree.

## 10-position connectors (FW2-to-FW2)

| Function | Device A pin | Device B pin | Requirement |
| --- | ---: | ---: | --- |
| I2C1 SCL | 7 | 7 | Direct connection required by specification |
| I2C1 SDA | 9 | 9 | Direct connection required by specification |
| A AOUT0 to B AIN0 | 5 | 8 | Output-to-input test |
| B AOUT0 to A AIN0 | 8 | 5 | Reciprocal interpretation of test |
| A AOUT1 to B AIN1 | 3 | 6 | Output-to-input test |
| B AOUT1 to A AIN1 | 6 | 3 | Reciprocal interpretation of test |
| A PROG VOUT to B AIN2 | 10 | 4 | Through a 10k/10k divider; measurement = 2 x B AIN2 |
| B PROG VOUT to A AIN2 | 4 | 10 | Through a 10k/10k divider; measurement = 2 x A AIN2 |
| Ground | 1 | 1 | Common return |
| AIN3 | 2 | 2 | Source specification says `xxx`; no destination assigned |

AIN3 is brought to one test pad per FW2, with no cross-connection. The
programmable output can reach 5.5 V while the published ADC range is 0-5 V;
rev A adds the two dividers above. Verify ADC loading, settling, and scaling
on the bench. See [the circuit design](../hardware/gpiojoiner/DESIGN.md).

## ORCA EEPROM on the shared I2C1 bus

Preserve the required 24LC02BT and the specified direct I2C1 connection.
Rev A uses **one EEPROM on the shared bus**, with EEPROM
SCL on both FW2 10-position pin-7 nets and SDA on both pin-9 nets. The
EEPROM is powered through a BAT54C common-cathode diode OR from the two
FW2 3.3 V outputs, with 100 nF decoupling and WP grounded. The diode OR
avoids directly joining host supply outputs; shared signal pins still
require both connected hosts to be powered before driving the bus.

For the SOT-23 `24LC02BT-E/OT` package: pin 1 SCL, pin 2 GND, pin 3 SDA,
pin 4 VCC, and pin 5 WP. Provide decoupling and a defined WP state.
The reference example incorrectly labels pin 5 NC. Two of these EEPROMs
cannot be assigned independent I2C addresses on the same bus because the
three low address bits are ignored. If separate per-host identification
is later required, it needs a circuit that still supports the specified
direct I2C1 test connection.

These are component requirements from
[Microchip DS20001709L, sections 2 and 5](https://ww1.microchip.com/downloads/en/DeviceDoc/24AA02-24LC02B-24FC02-Data-Sheet-20001709L.pdf).
Use verified 3.3 V pull-ups, reserve 0x50-0x57, use at most 400 kHz, and
coordinate host bus ownership. R5/R6 pull-ups are DNP pending measurement.
EEPROM identification contents and host behavior still need bench validation.

## Four-position, two-device application

The user clarified that generally two devices are connected. Rev A uses
the fixed sides defined above, supporting FW2/FW2, OG/OG, FW2 A/OG B, and
OG A/FW2 B. The alternative connectors on a side share signals. Four
simultaneously attached devices or two on the same side are unsupported;
that would require a separate switching/isolation design.

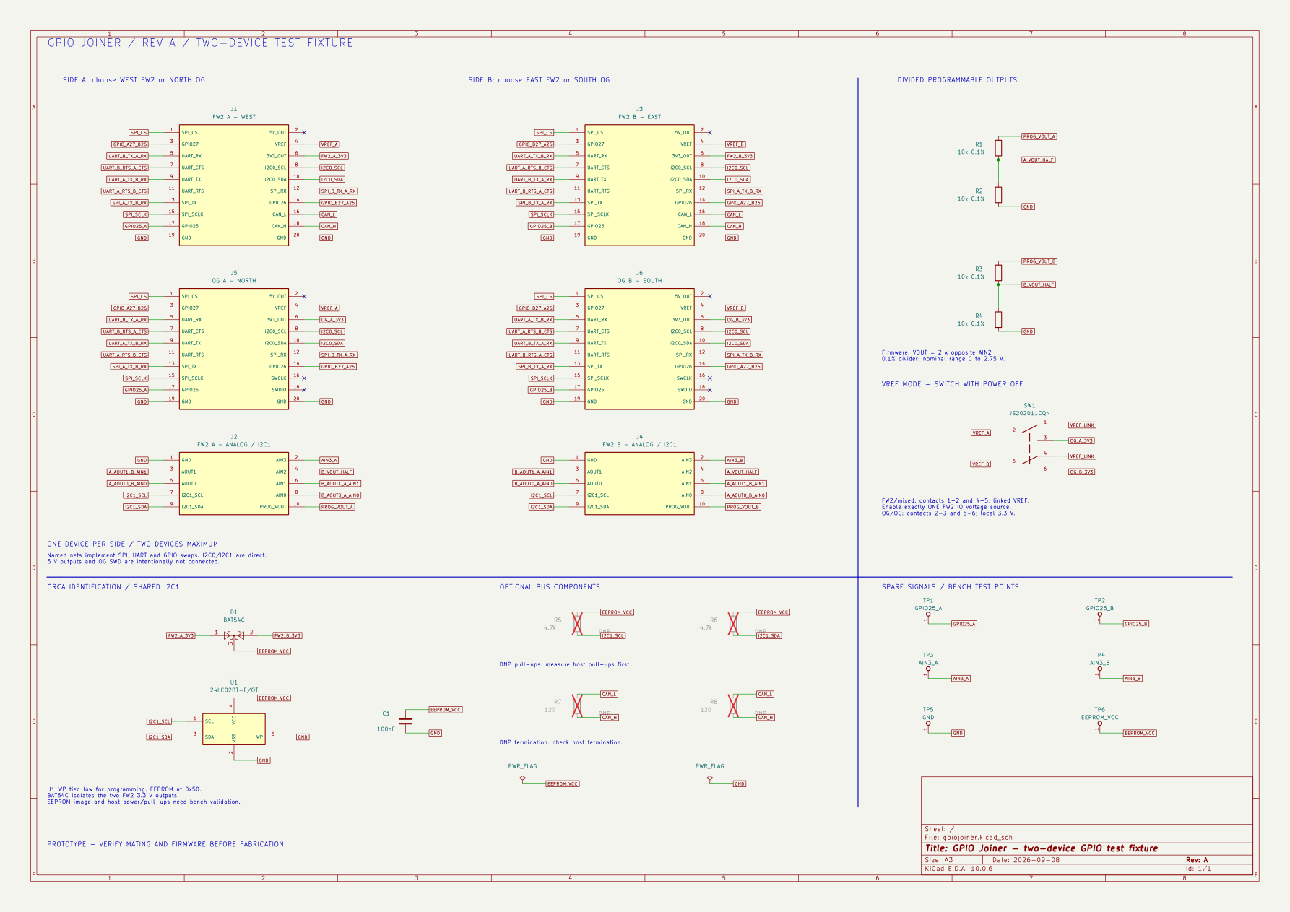
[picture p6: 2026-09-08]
examples/gpiojoiner/hardware/gpiojoiner/previews/schematic.png

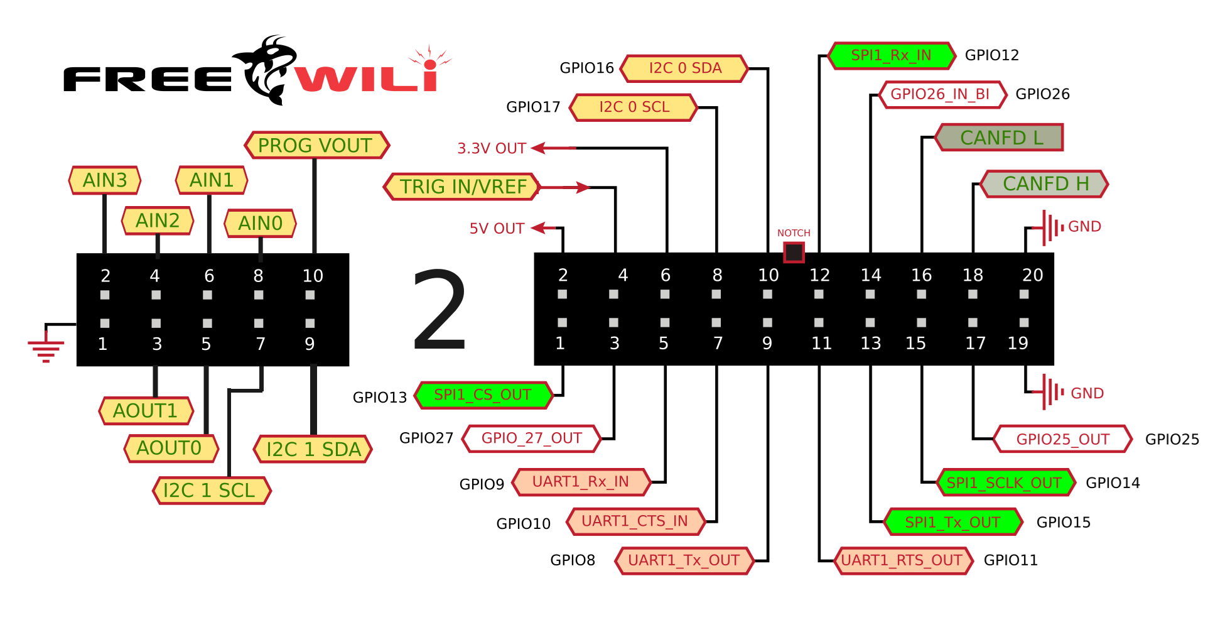
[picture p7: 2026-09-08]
examples/gpiojoiner/assets/freewili2connector.png

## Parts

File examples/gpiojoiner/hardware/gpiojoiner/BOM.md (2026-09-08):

# GPIO Joiner rev A - prototype assembly BOM

| References | Qty | Part / specification | Package | Assembly |
| --- | ---: | --- | --- | --- |
| J1, J3, J5, J6 | 4 | SFH11-PBPC-D10-RA-BK, 20-position right-angle connector from ORCA starter | Project-local ORCA_20_RA | Fit; verify mating before ordering |
| J2, J4 | 2 | SFH11-PBPC-D05-RA-BK, 10-position right-angle connector from ORCA starter | Project-local ORCA_10_RA | Fit; verify mating before ordering |
| SW1 | 1 | C&K JS202011CQN, DPDT slide switch | Project-local corrected SW_JS202011CQN | Fit; verify both contact states |
| U1 | 1 | Microchip 24LC02BT-E/OT, 2-kbit serial EEPROM | SOT-23-5 | Fit blank; ORCA image/programming remains to be validated |
| D1 | 1 | Nexperia BAT54C,215, dual Schottky diode, common cathode | SOT-23 | Fit |
| C1 | 1 | YAGEO CC0603KRX7R9BB104, 100 nF, X7R, 50 V, 10% | 0603 / 1608 metric | Fit |
| R1-R4 | 4 | YAGEO RT0603BRD0710KL, 10 kohm, 0.1%, 0.1 W | 0603 / 1608 metric | Fit; 2:1 analog dividers |
| R5, R6 | 2 | 4.7 kohm, 1%, at least 0.1 W | 0603 / 1608 metric | DNP; optional I2C1 pull-ups |
| R7, R8 | 2 | 120 ohm, 1%, at least 0.1 W | 0603 / 1608 metric | DNP; optional CAN termination |

TP1-TP6 are etched copper test pads, not purchased components. H1-H4 are
3.2 mm non-plated mounting holes; support hardware depends on the final
mechanical installation. There are 14 normally populated components and
four optional resistor positions, excluding copper pads and mounting holes.

Connector part numbers are those named in the upstream starter, not a
verified procurement substitution. Local footprints preserve its pad
coordinates, dimensions, and drill sizes. Confirm parts against actual
devices before ordering the prototype assembly.

Supplier-ready [PCBWay BOM](manufacturing/revA/assembly/pcbway-bom.csv) and
[JLCPCB BOM](manufacturing/revA/assembly/jlcpcb-bom.csv) contain exact orderable
MPNs and catalog identifiers, with source links in the PCBWay file. Catalog
stock, substitutions and assembly charges require confirmation in a live quote.
Use the [manufacturing instructions](manufacturing/revA/README.md).

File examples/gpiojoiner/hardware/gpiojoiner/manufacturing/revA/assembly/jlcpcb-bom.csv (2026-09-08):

Comment | Designator | Footprint | LCSC Part #
SFH11-PBPC-D10-RA-BK | J1,J3,J5,J6 | ORCA_20_RA | C3319874
SFH11-PBPC-D05-RA-BK | J2,J4 | ORCA_10_RA | C3322376
JS202011CQN | SW1 | SW_JS202011CQN | C221663
24LC02BT-E/OT | U1 | SOT-23-5 | C2061350
BAT54C,215 | D1 | SOT-23 | C37704
CC0603KRX7R9BB104 | C1 | C_0603_1608Metric | C14663
RT0603BRD0710KL | R1,R2,R3,R4 | R_0603_1608Metric | C95204

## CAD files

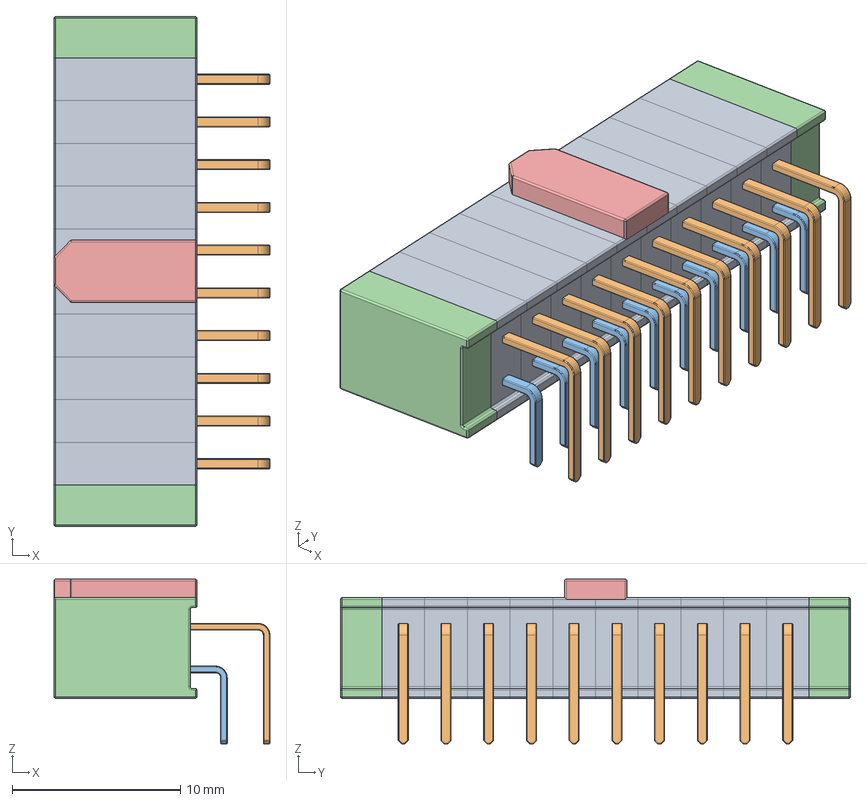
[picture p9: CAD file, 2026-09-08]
examples/gpiojoiner/hardware/gpiojoiner/models/ORCA_20_RA.step
12.8 x 30.3 x 9.80 mm

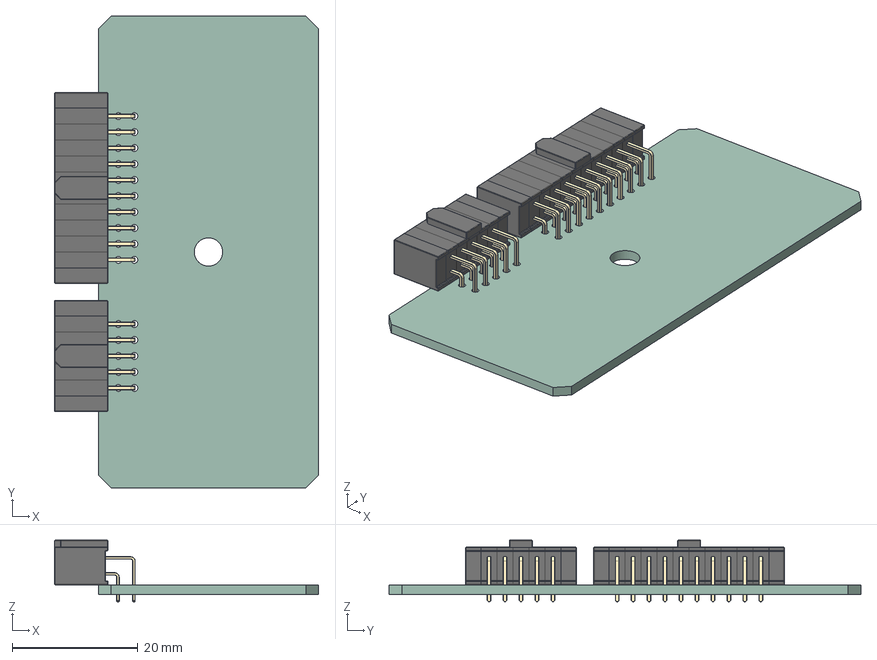
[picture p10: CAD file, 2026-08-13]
kicad/ORCATemplate.step
42.0 x 75.0 x 9.80 mm
body section with RA gold pins x 19
end x 4
Polarizing Key x 2
ORCATemplate_PCB

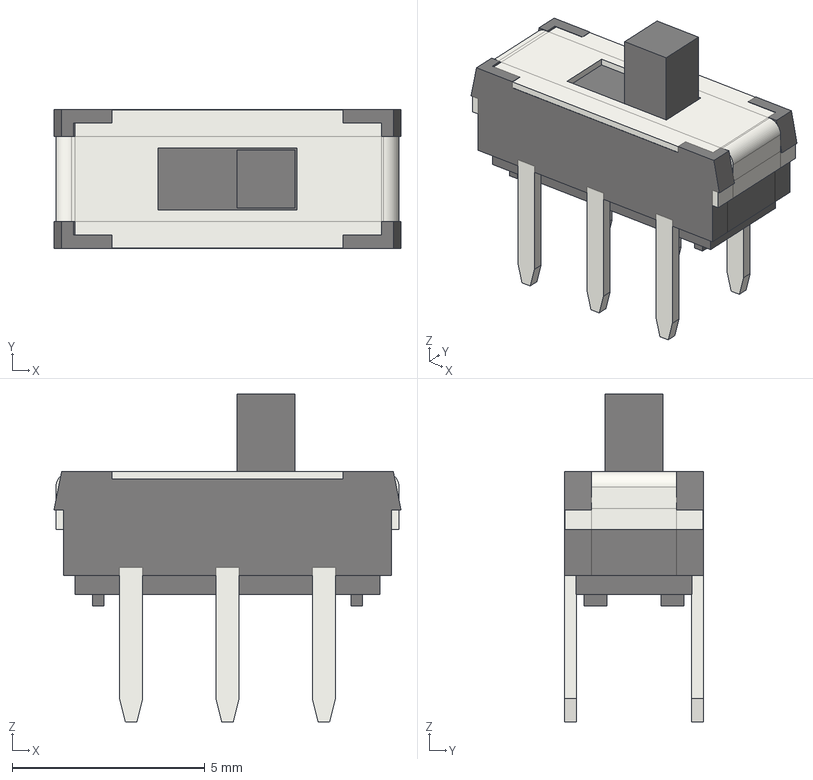
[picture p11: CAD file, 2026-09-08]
examples/gpiojoiner/hardware/gpiojoiner/models/SW_CK_JS202011CQN_DPDT_Straight.step
9.00 x 3.61 x 8.50 mm

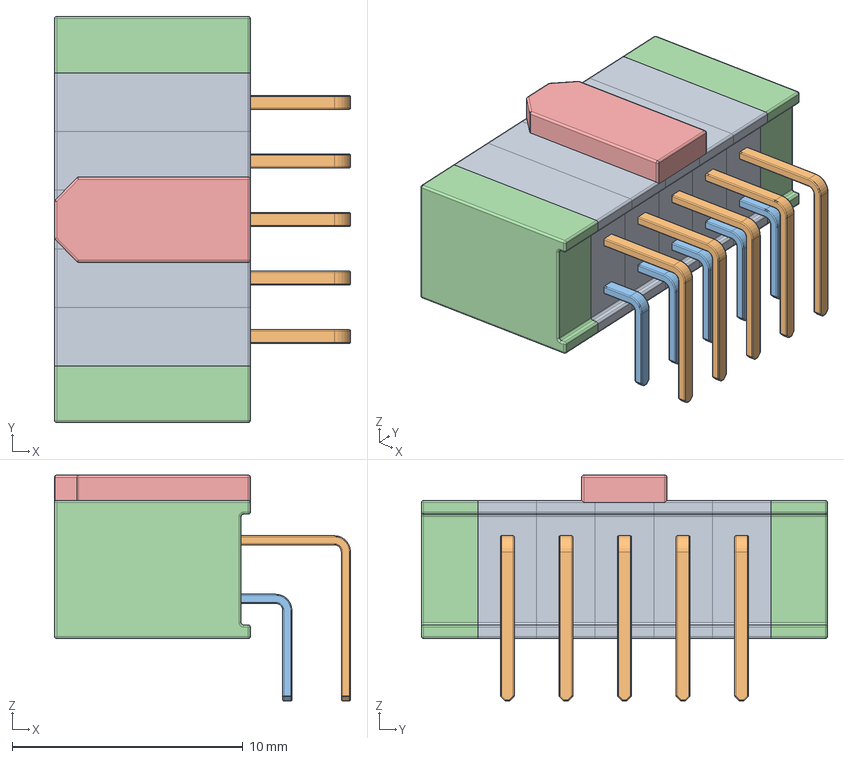
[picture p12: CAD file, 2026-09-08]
examples/gpiojoiner/hardware/gpiojoiner/models/ORCA_10_RA.step
12.8 x 17.6 x 9.80 mm

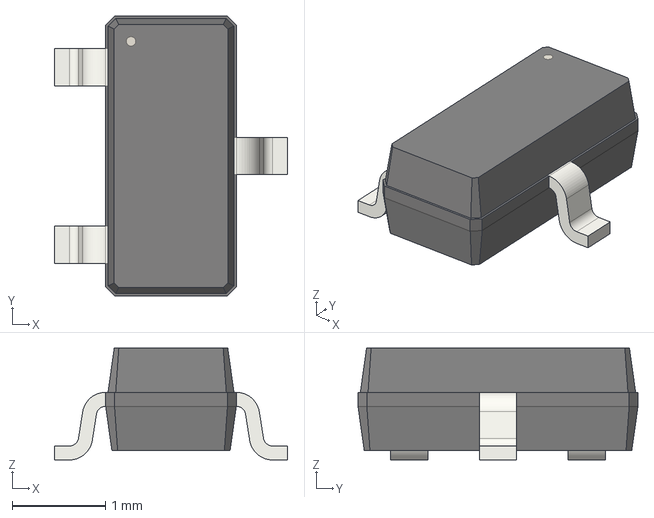
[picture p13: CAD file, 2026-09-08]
examples/gpiojoiner/hardware/gpiojoiner/models/SOT-23.step
2.50 x 3.00 x 1.20 mm

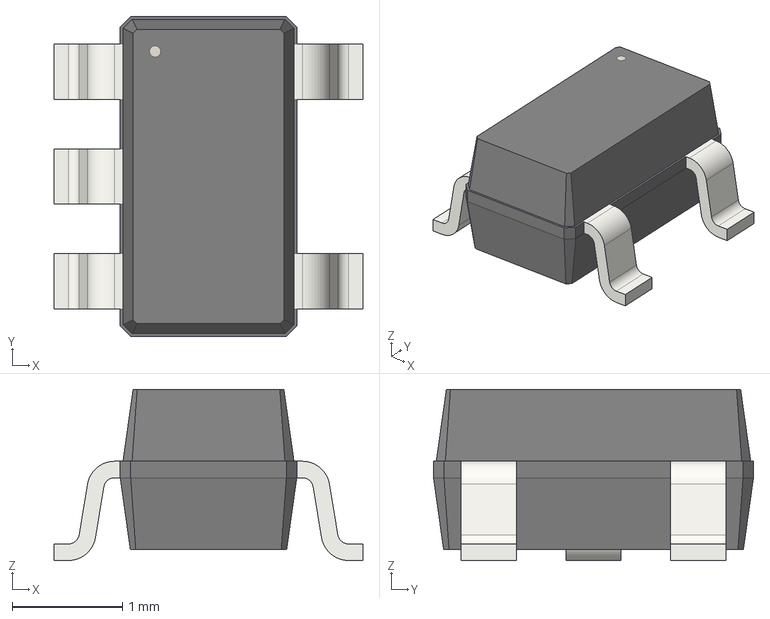
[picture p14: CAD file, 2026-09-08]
examples/gpiojoiner/hardware/gpiojoiner/models/SOT-23-5.step
2.80 x 2.90 x 1.55 mm

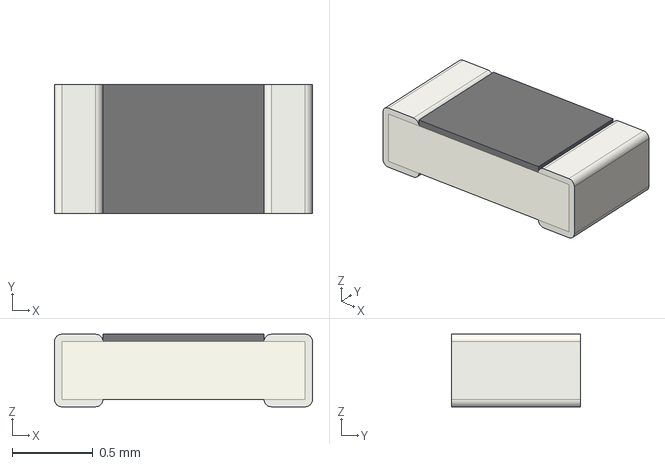
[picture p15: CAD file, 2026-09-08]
examples/gpiojoiner/hardware/gpiojoiner/models/R_0603_1608Metric.step
1.60 x 0.8 x 0.45 mm

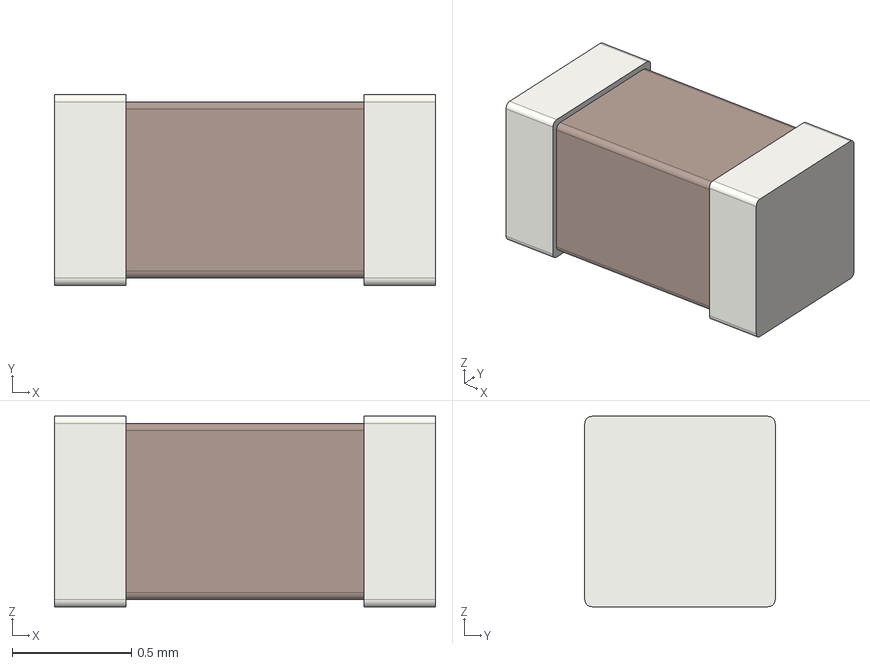
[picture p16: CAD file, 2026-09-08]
examples/gpiojoiner/hardware/gpiojoiner/models/C_0603_1608Metric.step
1.60 x 0.8 x 0.8 mm

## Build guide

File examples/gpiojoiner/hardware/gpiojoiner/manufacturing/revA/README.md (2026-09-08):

# GPIO Joiner rev A - prototype manufacturing package

Prepared 2026-09-08 for **five fully assembled prototypes** as a working quote
quantity. These are manufacturing inputs for supplier quotation and engineering
review. No supplier upload, quote, purchase, physical mating test or bench test
has been completed.

The board has four docking positions but supports **two connected devices,
one per electrical side**. The 24LC02BT EEPROM is included on the shared
FW2 I2C1 bus. It will arrive blank unless a separately validated image and
programming service are added to the order.

## Files to use

| File | Use |
| --- | --- |
| `gpiojoiner-revA-gerbers.zip` | Upload to the PCB fabrication Gerber input. Eight Gerber layers, separate PTH/NPTH drill files and IPC-D-356 electrical test netlist. |
| `gpiojoiner-revA-assembly.zip` | Complete quote/reference package. Unzip and use its supplier-specific BOM and CPL files in the assembly inputs. |
| `assembly/pcbway-bom.csv` | PCBWay turnkey BOM: seven line items, 14 components per board. Quantities are per board. |
| `assembly/pcbway-cpl.csv` | PCBWay centroid: seven SMD parts only, as requested by its file guide. Through-hole locations are in the assembly drawing. |
| `assembly/jlcpcb-bom.csv` | JLCPCB BOM with exact MPNs and LCSC catalog numbers. |
| `assembly/jlcpcb-cpl.csv` | JLCPCB placement file: all 14 fitted components. |
| `drawings/gpiojoiner-revA-manufacturing.pdf` | Three-page 1:1 fit sheet, complete assembly layout, component orientation and fabrication notes. |
| `manufacturing-checks.md` | Independent checks of the exported files against the verified CAD. |
| `SHA256SUMS.txt` | Content checksums, including the verified source CAD revision. |

Only the named ZIP is intended for the PCB Gerber uploader. The development
`checks/` directory contains temporary build data and is excluded from both ZIPs.
The Gerber paste layer has **18 apertures** for the seven fitted SMD parts;
there are no stencil apertures at R5-R8 and no bottom-side paste file.

## Quote settings

| Setting | Selection |
| --- | --- |
| Quantity | 5 finished boards; assemble all 5 (working assumption) |
| PCB | Rigid FR-4, 2 copper layers, 1.60 mm finished thickness |
| Size | 130 x 130 mm bounding box; one cross-shaped PCB design |
| Copper | 1 oz / 35 micrometers on each outer layer |
| Finish | Lead-free ENIG |
| Solder mask / legend | Green mask; white legend on both sides |
| Profile | CNC routed; no V-score, castellations, edge plating or controlled impedance |
| Corners | Normal internal routing radii up to 1 mm acceptable |
| Holes | 158 plated: 100 connector pins, 6 switch pins, 52 vias; 4 non-plated 3.2 mm support holes |
| Via treatment | Solder mask as supplied; no resin filling or via-in-pad process |
| Electrical test | Required; use supplied IPC-D-356 and Gerbers |
| Assembly | Lead-free, top side; 7 SMD + 7 through-hole components per board |
| Optional parts | R5, R6, R7, R8: DO NOT POPULATE |
| Programming / functional test | Not included; U1 blank; no test firmware or factory fixture supplied |
| Panelization | Supplier to propose temporary rails, fiducials, tabs and assembly tooling; deliver depanelized boards |

The routed design uses 0.20 mm tracks, 0.15 mm copper clearance, 0.30 mm
copper-to-edge clearance, 0.4 mm via drills in 0.8 mm pads, and a minimum
0.25 mm annulus at the switch pins. Minimum legend size is 1.0 mm with
0.15 mm strokes. Keep the quoted copper at **1 oz**: JLCPCB's published
2 oz spacing requirement is larger than this board's clearance.
[JLCPCB capabilities](https://jlcpcb.com/capabilities/pcb-capabilities).

For PCBWay, request engineering confirmation of **0.15 mm spacing and
0.25 mm component-hole annulus** against the chosen service; do not assume
its lowest-cost 6 mil spacing / 10 mil annulus process applies. Its capability
table includes finer options. [PCBWay capabilities](https://www.pcbway.com/capabilities.html).

## Supplier workflow

1. Print page 1 of the manufacturing PDF at **100% / Actual size** on US
   Letter paper. Confirm both axes of the 50 mm calibration square. Compare
   actual connectors and FW2/OG devices with the hole pattern: pin 1, gender,
   key, mating direction, 26.72 mm FW2 connector spacing, and enclosure clearance.
   The drawing does not represent the device cases.
2. Upload the Gerber ZIP and select the settings above. Choose PCB assembly
   and upload that supplier's BOM/CPL pair plus the manufacturing PDF.
   For a full-service quote, request all components sourced and fitted.
3. Request mixed SMD/through-hole assembly, including all six outward-facing
   connectors and the switch. Their bodies overhang the outline. Let the
   factory propose hand soldering, selective/wave soldering and any fixture.
   Review the panel/tooling drawing before releasing production.
4. Check every supplier-selected MPN, quantity and placement overlay. Compare
   U1/D1 pin 1 and SW1 numbering with page 3. Native KiCad footprint origins
   are used: through-hole datums are not necessarily plastic-body centers.
   Align connector models to the drilled pad pattern. Do not accept automatic
   substitutions or guessed placement-rotation offsets.
5. Confirm the actual switch has the documented contact states: left 1-2 and
   4-5; right 2-3 and 5-6. This can be checked on a sample switch, or requested
   as an assembler first-article check before fitting the batch. Then review
   the itemized total, parts availability, lead time and shipping before payment.

PCBWay's published file guide supports the supplied RS-274X Gerbers, CSV
turnkey BOM and SMD-only centroid. Additional assembly drawings are expressly
recommended. [PCBWay file requirements](https://www.pcbway.com/assembly-file-requirements.html).
JLCPCB's KiCad guide specifies the BOM/CPL columns used here.
[JLCPCB KiCad export guide](https://jlcpcb.com/help/article/how-to-generate-the-bom-and-centroid-file-from-kicad).

Exact catalog references are recorded in each PCBWay BOM source cell and in
`parts.json` inside the complete package. Catalog presence does not establish
current stock, service eligibility, price or delivery date. A live quote must
confirm all of these, particularly the through-hole connector fixture/assembly.

## Notes to include with the quote

> Please quote five GPIO Joiner rev A prototypes, fully turnkey, with all
> fourteen listed components fitted per board. This is a 130 x 130 mm cross,
> 2-layer FR-4, 1.6 mm, 1 oz copper, green mask, white legend, ENIG. Seven
> parts are SMD and seven are through-hole. The six right-angle connectors
> overhang the board. Please review 0.15 mm copper spacing, 0.25 mm switch-pad
> annulus, panel/fixture needs, connector orientation and all polarized parts.
> R5-R8 are DNP. Fit the EEPROM blank; programming and functional test are
> not supplied. Please return an itemized quote, availability, engineering
> questions, and placement/panel previews for review before production.

This is prepared text; it has not been sent to either supplier.

## After the prototypes arrive

Inspect one board and check continuity before connecting devices. Validate
VREF selection, EEPROM supply/read/write, I2C pull-ups and ownership, CAN
termination, and analog divider behavior with controlled bench bring-up.
Use one device per side and change SW1 with power off. Programmable VOUT
readback is twice the opposite AIN2 value. A product-specific ORCA ID image
and boot-detection test remain to be developed. Bench validation is required
before treating this revision as a production design.

## Reproduce

Run `tools/verify_project.py` with KiCad Python, then
`tools/export_manufacturing.py` with the same Python. The exporter refuses
CAD hashes not present in the verification report. Run `build_assembly.mjs`
with Node and an artifact-tool runtime, `make_manufacturing_drawings.py`
with ReportLab, `check_manufacturing.py` with Gerbonara, and `render_cam.mjs`
with Node/sharp. Visually inspect the PDF, supplier tables and Gerber views,
then run `package_manufacturing.py` with standard Python. These scripts live
in `hardware/gpiojoiner/tools/`; regeneration replaces generated outputs.

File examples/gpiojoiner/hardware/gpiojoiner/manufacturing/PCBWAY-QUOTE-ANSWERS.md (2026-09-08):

# PCBWay quote-form answers — GPIO Joiner rev A

Checked 2026-09-08 against https://www.pcbway.com/quotesmt.aspx.
Working order: five PCBs, all five fully assembled. The component counts below
are per board. No form submission or order has been made.

## Assembly Service

| Field | Enter/select |
| --- | --- |
| Service option | Turnkey — PCBWay supplies all parts |
| Board type | Single pieces |
| Assembly side(s) | Top side |
| Quantity | 5 |
| Contains sensitive components/parts | Yes — use the handling note below |
| Accept alternatives/substitutes made in China? | No — exact BOM parts; review any proposed substitution separately |
| Select PCBWay's PCB Order# | No, unless you have since placed a separate PCB order for this revision |
| Add PO No. | Optional: GPIOJOINER-REVA-PROTOTYPE |
| Number of Unique Parts | 7 |
| Number of SMD Parts | 7 |
| Number of BGA/QFP Parts | 0 |
| Number of Through-Hole Parts | 7 |
| Depanel the boards to delivery | No for this single-piece quote; Yes if PCBWay changes to supplier panelization |
| Function test | No — no functional fixture/firmware supplied |
| Conformal coating | No |
| Firmware loading | No — EEPROM fitted blank |
| Press-fit assembly | No |
| Box build assembly | No |
| Cable wire harness assembly | No |
| Package box | Neutral box |
| Flying Probe Testing (assembly add-on) | No; request bare-PCB open/short electrical test in the notes |
| Number of X-ray test | 0 |

Counts exclude R5-R8 (DNP), copper test pads and mounting holes. The seven
SMD components have 18 solder pads; the seven THT components have 106 pins.
Enter **7 and 7** in the component-count fields, not 18/106 and not the
five-board totals. The form tooltips explicitly define these as parts per board.

Sensitive-component handling note (under the Yes selection):

> J1-J6: Sullins SFH11-PBPC-D10-RA-BK / SFH11-PBPC-D05-RA-BK, PBT housings. Fit after SMD reflow and observe Sullins soldering limits. SW1: C&K JS202011CQN; follow manufacturer soldering/cleaning instructions and verify contact states against the assembly drawing before fitting the batch.

The Sullins series has specified processing-temperature limits; this note
draws attention to the through-hole assembly sequence.
[Manufacturer datasheet](https://s3.amazonaws.com/catalogspreads-pdf/PAGE123%20.100%20SFH11%20SERIES%20FEMALE%20HDR%20ST%20RA.pdf).

Paste into **Detailed information of assembly**:

> GPIO Joiner rev A: quote five fully assembled boards, 14 fitted components per board (7 SMD and 7 through-hole), using the exact BOM. R5-R8 are DO NOT POPULATE. Fit U1 24LC02BT-E/OT blank; no EEPROM programming or functional-test firmware is supplied. Install SMD parts before the six outward-facing right-angle connectors and the slide switch. Connector bodies overhang the PCB: please confirm assembly fixture/temporary rail requirements and any extra charges. Deliver five individual boards. Use the assembly PDF for connector orientation, U1/D1 pin numbering and SW1 contact states. Verify SW1 left contacts 1-2 and 4-5, right contacts 2-3 and 5-6. The CPL lists the seven SMD parts; THT placement is in the drawing. Return placement/tooling previews and any engineering questions before production.

## PCB Specifications

Enable **PCB Specifications**, because no separate PCB order has been placed.

| Field | Enter/select |
| --- | --- |
| Board type | Single pieces |
| Different design in panel | 1, if displayed |
| Size (single) | Length 130 mm × Width 130 mm |
| Quantity (single) | 5 |
| Layers | 2 Layers |
| Copper layer / soldermask / silkscreen sides, if shown | Top and bottom; these controls may only appear for a one-layer board |
| Material | FR-4 |
| FR4-TG | S1000H TG150 / the standard TG150 option |
| Thickness | 1.6 mm |
| Min track/spacing | 5/5 mil |
| Min hole size | 0.3 mm ↑ — actual minimum drill is 0.4 mm |
| Solder mask | Green |
| Silkscreen | White |
| UV printing / Multi-color | None |
| Edge connector | No — this means PCB gold fingers, not the mounted GPIO connectors |
| Bevelling | No / not applicable |
| Surface finish | Immersion gold (ENIG) |
| Thickness of Immersion Gold | 2U" (2 microinches), recommended quote choice |
| Via process | Tenting vias; preserve the supplied mask Gerbers |
| Finished copper | 1 oz Cu |
| Inner Copper | Not applicable to a 2-layer PCB |
| Remove product No. | No — allow PCBWay's manufacturing identifier |
| Peelable soldermask | None |
| Hole copper thickness | Standard (20um) |
| UL marking | None |
| Date code | None — leave the existing design date unchanged |
| Package box | Neutral box |
| Add serial numbers | No / None |
| Serial Number Printing Location | Not applicable |
| Add PO No. | Optional: GPIOJOINER-REVA-PROTOTYPE |

Leave all other special-process boxes unchecked: castellations, edge plating,
impedance control, halogen-free, custom stackup, carbon ink, resin-filled/capped
vias, via-in-pad, press-fit holes, countersink/counterbore, Z-axis milling,
black FR4 core, embedded copper, cavities, semi-flex, hybrid PCB, back drilling,
selective hard-gold special processing and paper between boards.
Rogers/aluminum/copper-base parameters do not apply.

The actual routing is 0.20 mm track / 0.15 mm clearance (about 7.87/5.91 mil),
so choose the 5/5 mil category. The board outline is a cross; 130 × 130 mm is
its bounding box. Its vias are tented in the supplied mask files.

Paste into **Other special request**:

> GPIO Joiner rev A, five individual cross-shaped PCBs, 130 x 130 mm bounding box, 2-layer FR-4, 1.60 mm, 1 oz copper, green mask, white legend, ENIG 2 microinch gold. CNC-route the outline; no V-score. Normal internal router radii up to 1 mm are acceptable. Please review 0.15 mm copper spacing and 0.25 mm switch-pad annulus. There are 158 plated holes and four 3.2 mm NPTH mounting holes; minimum drill 0.4 mm. Bare-PCB open/short electrical test is required; IPC-D-356 is included. For assembly, please advise whether temporary rails, panelization or a fixture is required and return its drawing/cost before production. Do not relocate connectors or change the individual board geometry.

If PCBWay requests panelization after engineering review, change the assembly
Board type to Panelized PCBs and the PCB Board type to Panel by Supplier.
Select break-away rails Yes, one design, depanel for delivery Yes, and
X-out allowance Not Accept for this small prototype run. Ask PCBWay to choose
the panel arrangement/CNC tab routing. Continue to specify **five individual
finished boards**, not five panels; confirm any quantity change before payment.
Panel dimensions and tab locations are to be supplied by their engineer.

## File upload step

The prepared files are under `hardware/gpiojoiner/manufacturing/revA/`.

| Upload field | File |
| --- | --- |
| PCB / Gerber | `gpiojoiner-revA-gerbers.zip` |
| BOM | `assembly/pcbway-bom.csv` |
| Pick-and-place / centroid | `assembly/pcbway-cpl.csv` |
| Assembly drawing / other documents | `drawings/gpiojoiner-revA-manufacturing.pdf` |
| Schematic, if requested | `drawings/gpiojoiner-revA-schematic.pdf` |
| One combined assembly/reference upload, if offered | `gpiojoiner-revA-assembly.zip` |

Use the individual BOM and CPL CSVs in their designated inputs. PCBWay accepts
CSV BOMs and allows THT references to be omitted from the centroid when their
placement is otherwise documented.
[PCBWay assembly file guide](https://www.pcbway.com/smt_ordering_guide.html).

## Your account / shipping choices

- Email: your PCBWay account/contact email.
- Shipping destination/address: your actual receiving address.
- Shipping method: choose the service whose quoted cost and delivery time suit you.
- Build time: standard/non-expedited unless you need a deadline.
- Target price: leave blank.
- Content-policy/export declaration: read and confirm personally; it is not a CAD parameter.
- Review the itemized total including components, fabrication, assembly, tooling,
  shipping and tax. The initial assembly calculation is not the final turnkey price.

Check the 1:1 fit sheet against real devices and review the supplier's final
engineering/placement previews before ordering the prototypes.

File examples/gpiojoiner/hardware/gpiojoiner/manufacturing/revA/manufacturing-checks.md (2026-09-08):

# Rev A manufacturing export checks

Generated 2026-09-08T23:23:16+00:00.
Independent Gerbonara CAM parser compared with the verified KiCad geometry.

- PASS: source schematic, PCB and project hashes match fresh CAD verification.
- PASS: eight Gerber graphic layers; twelve outline edges; 130 x 130 mm centerline bounds.
- PASS: all 162 drill positions and diameters match CAD within 0.000501 mm (158 plated, four non-plated).
- PASS: minimum hole edge gap 0.631 mm.
- PASS: 18 stencil apertures match the seven fitted SMD parts; all four DNP resistor positions omitted.
- PASS: IPC-D-356 parses 194 records: 138 electrical pads, 52 vias, four mounting holes.
- PASS: all 138 IPC pad coordinates match CAD within 0.0013 mm; exported net names preserve connectivity groups.
- PASS: both supplier BOMs contain seven exact-MPN lines, 14 fitted references and no DNP/TP/holes.
- PASS: JLCPCB CPL includes 14 fitted parts; PCBWay CPL includes seven SMD parts per its published file requirements. All listed coordinates, sides and rotations match CAD; common Gerber/drill/CPL datum.
- Generated independent top/bottom Gerber SVG previews for visual review. Use render_cam.mjs for PNGs (SVG filters require a compatible renderer).

The native IPC-D-356 uses 0.0001-inch resolution; its datum matches the metric Gerbers.
CPL values remain KiCad footprint datums; manufacturer placement overlays need review,
especially the connector bodies, switch and polarized parts. No assembly-machine
rotation corrections are guessed here. This is prototype quotation data; manufacturer
DFM acceptance, physical mating, EEPROM identity and bench operation are unverified.

## Parser observations

- gpiojoiner-NPTH.drl:12 "G90": G90 header statement found after end of header
- gpiojoiner-PTH.drl:16 "G90": G90 header statement found after end of header

KiCad emits G90 after the Excellon header. Gerbonara accepts and applies this
absolute-coordinate statement, while reporting its header placement. All drill
hits parsed and matched the CAD snapshot; the native KiCad drill files are retained.

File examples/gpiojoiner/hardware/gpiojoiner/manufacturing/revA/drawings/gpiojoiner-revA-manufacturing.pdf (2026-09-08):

# Mechanical fit check - print at 100%

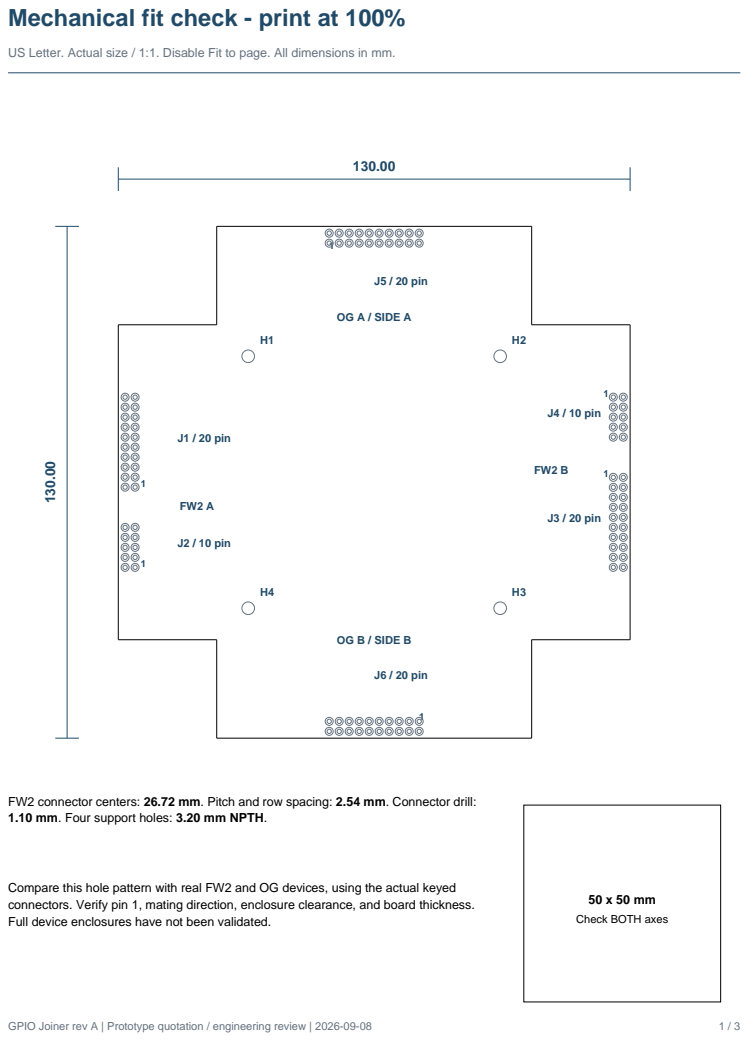
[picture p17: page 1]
GPIO Joiner rev A | Prototype quotation / engineering review | 2026-09-08; J4 / 10 pin; J3 / 20 pin; J1 / 20 pin; J2 / 10 pin; J5 / 20 pin; J6 / 20 pin; OG A / SIDE A; OG B / SIDE B

US Letter. Actual size / 1:1. Disable Fit to page. All dimensions in mm.

FW2 connector centers: 26.72 mm. Pitch and row spacing: 2.54 mm. Connector drill:
1.10 mm. Four support holes: 3.20 mm NPTH.

Compare this hole pattern with real FW2 and OG devices, using the actual keyed
connectors. Verify pin 1, mating direction, enclosure clearance, and board thickness.
Full device enclosures have not been validated.

Check BOTH axes

# Assembly placement reference

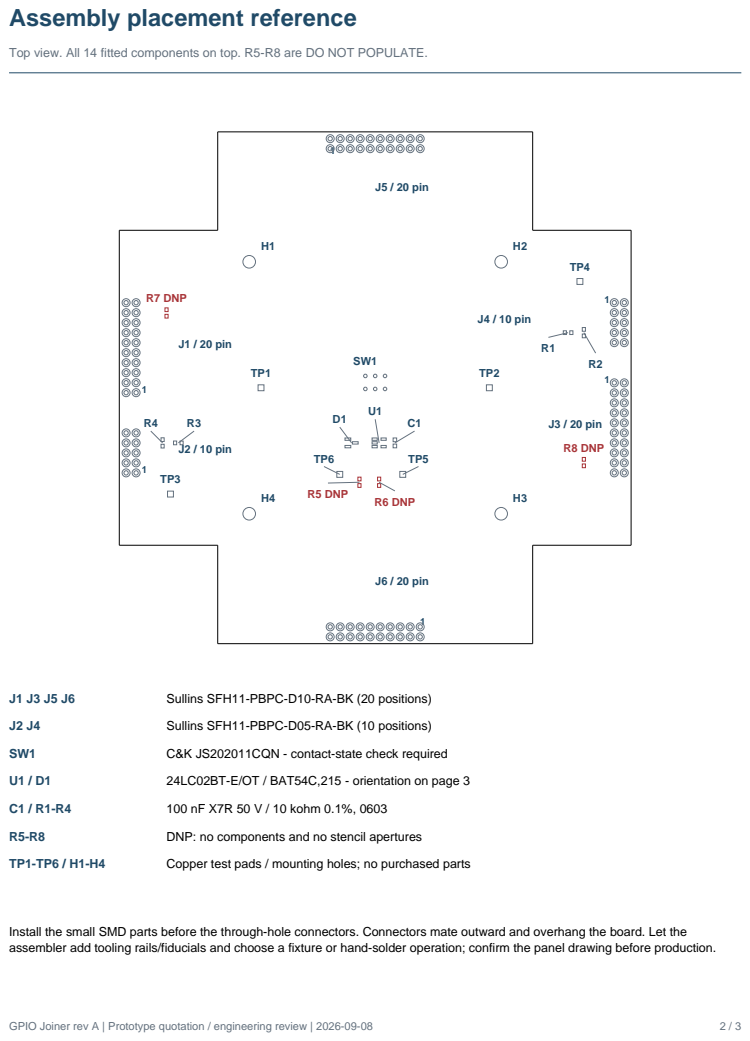
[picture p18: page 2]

Top view. All 14 fitted components on top. R5-R8 are DO NOT POPULATE.

Install the small SMD parts before the through-hole connectors. Connectors mate outward and overhang the board. Let the
assembler add tooling rails/fiducials and choose a fixture or hand-solder operation; confirm the panel drawing before production.

# Assembly details and fabrication notes

Pin numbers below are PCB pad numbers. Check package markings and supplier placement preview.

GPIO Joiner rev A | Prototype quotation / engineering review | 2026-09-08 | 3 / 3

## U1 - TOP VIEW

SCL | 1
GND | 2
SDA | 3 | 4 | VCC

### 5 WP / GND

## D1 - TOP VIEW

FW2 A 3V3 | 1
FW2 B 3V3 | 2

### 3 EEPROM VCC

## SW1 - TOP VIEW

1 | 2 | 3
4 | 5 | 6

VREF slide switch
Left: pads 1-2 and 4-5 connected (FW2 / MIXED).
Right: pads 2-3 and 5-6 connected (OG / OG).
Verify with a meter on the actual part before fitting the batch. Never switch with devices powered.

Prototype quote: five boards as a working quantity. FR-4, two layers, 1.60 mm finished thickness, 1 oz finished copper, green solder mask, white legend both sides, lead-free ENIG finish.

Outline and holes: CNC-route the cross. 130 x 130 mm bounding box. No V-score or castellations. Finished holes: 158 plated, 4 non-plated. Allow normal inside router corner radii up to 1 mm. Electrical test required.

Assembly: seven SMD parts and seven through-hole parts per board. Four resistor positions are DNP. Do not substitute connectors, switch, EEPROM package, or diode configuration without review. Keep 0.1% divider resistors.

Coordinates: Gerber/drill/CPL origin is lower left of the board bounding box. X right, Y up, mm. CPL uses native KiCad footprint origins/rotations. Through-hole origins are placement datums, not necessarily plastic-body centers. Align vendor models using the actual hole/pad pattern and this drawing.

EEPROM: fit U1 blank. No programming image or factory functional test is supplied. During bring-up, use one I2C1 controller, verified 3.3 V pull-ups and at most 400 kHz. A programmed ORCA ID remains a separate task.

Use: one device per side, two total. Set VREF mode with power off. Programmable-output measurement is 2 x the opposite AIN2 value. Physical fit and bench operation remain unverified.

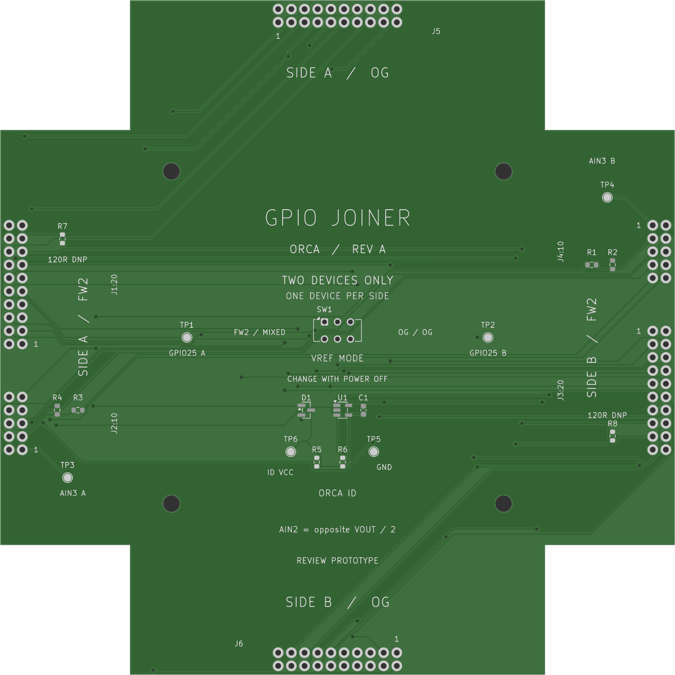
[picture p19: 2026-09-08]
examples/gpiojoiner/hardware/gpiojoiner/manufacturing/revA/drawings/gerber-top.png

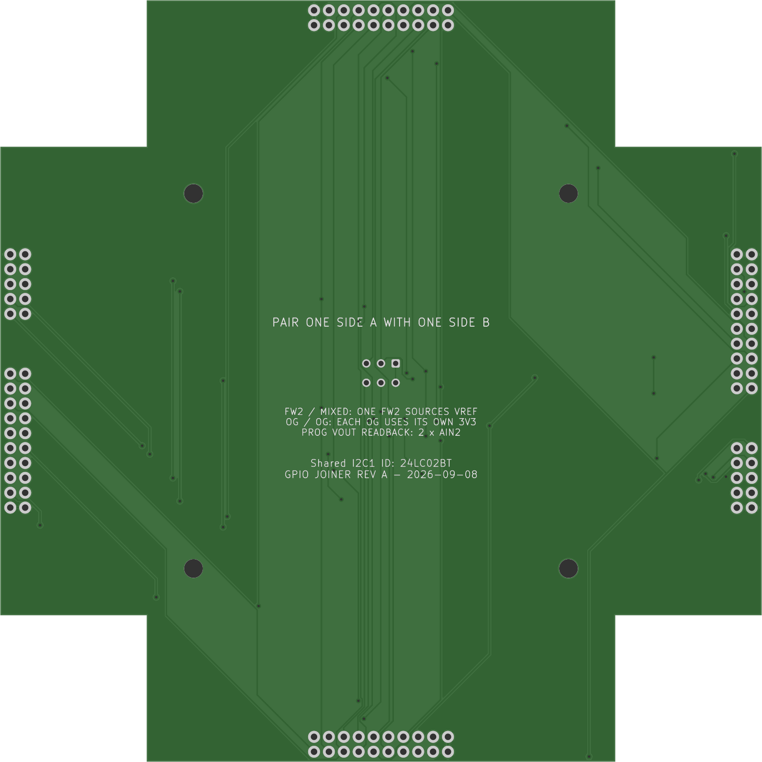
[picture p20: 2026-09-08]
examples/gpiojoiner/hardware/gpiojoiner/manufacturing/revA/drawings/gerber-bottom.png

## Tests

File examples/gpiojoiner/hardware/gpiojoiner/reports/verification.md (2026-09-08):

# Rev A CAD verification

Fresh verification: 2026-09-08T23:21:20+00:00.
KiCad 10.0.6. All commands exited 0.

- Schematic connection audit: **216 assertions passed**, including all four
  allowed device pairings, both VREF modes, EEPROM/supply isolation,
  analog dividers, CAN isolation, and required DNP parts.
- PCB audit: **138 schematic pad/net assignments passed**, plus connector
  geometry, corrected switch numbering, local models, board construction,
  design rules and absence of DRC exclusions.
- ERC: **0 violations**.
- DRC: **0 violations, 0 unconnected items, 0 schematic parity issues**.
  Reports use the project's enabled error/warning checks. KiCad's ignored
  check categories are explicitly listed in the JSON reports.

These automated checks do not establish visual review. Inspect the schematic
and current top, bottom and perspective previews separately before release.
Independent circuit and footprint review is recorded in
[circuit-review.md](circuit-review.md).

Configured minimums: 0.20 mm tracks, 0.15 mm copper clearance, 0.30 mm
copper-edge clearance, 0.15 mm silk clearance, 1.0 mm text height and
0.15 mm text thickness.
The board uses two copper layers, 1.6 mm thickness and a 130 x 130 mm
cross outline. There are 28 footprints including four mechanical holes.

These checks establish CAD connectivity and the configured design rules.
They do not establish enclosure fit, manufactured-board quality, signal
integrity at a specified speed, EEPROM identification or hardware operation.
The [setup and bench requirements](../README.md) remain prerequisites to release.

## Reproduce

Run `tools/verify_project.py` with KiCad's bundled Python. It re-exports
the actual schematic netlist, runs both independent audits, runs ERC in
JSON and text formats, and runs DRC with zone refill and schematic parity.
It stops on a failing command and refreshes this report only on success.

## Verified file SHA-256

- `gpiojoiner.kicad_sch`: `eea3e45c28ea3d7d3a0ca2fb27f6ecfe00bd261af3fdb921f23457043e6cb70f`
- `gpiojoiner.kicad_pcb`: `28bcf821207bb0a78fc67c70718cc22cc994a2f24c78a07c4d349115c0c0c7f3`
- `gpiojoiner.kicad_pro`: `51b380ce64545851a422f7cbc25708f096ab6f13b1da3c1fffd300cb95f5d95e`

## Command output

```text

PASS: 216 connection/value assertions; four device pairings, both VREF modes, 37 exact copper-net groups.
Found 0 violations
Saved ERC Report to reports/erc.json
Found 0 violations
Saved ERC Report to reports/erc.rpt
Found 0 violations
Found 0 unconnected items
Found 0 schematic parity issues
Saved DRC Report to reports/drc.json
Saved board
PASS: 138 schematic pad/net assignments; 6 docking connectors; FW2 spacing/orientation; corrected switch; DNPs; 4 holes; local models.
```

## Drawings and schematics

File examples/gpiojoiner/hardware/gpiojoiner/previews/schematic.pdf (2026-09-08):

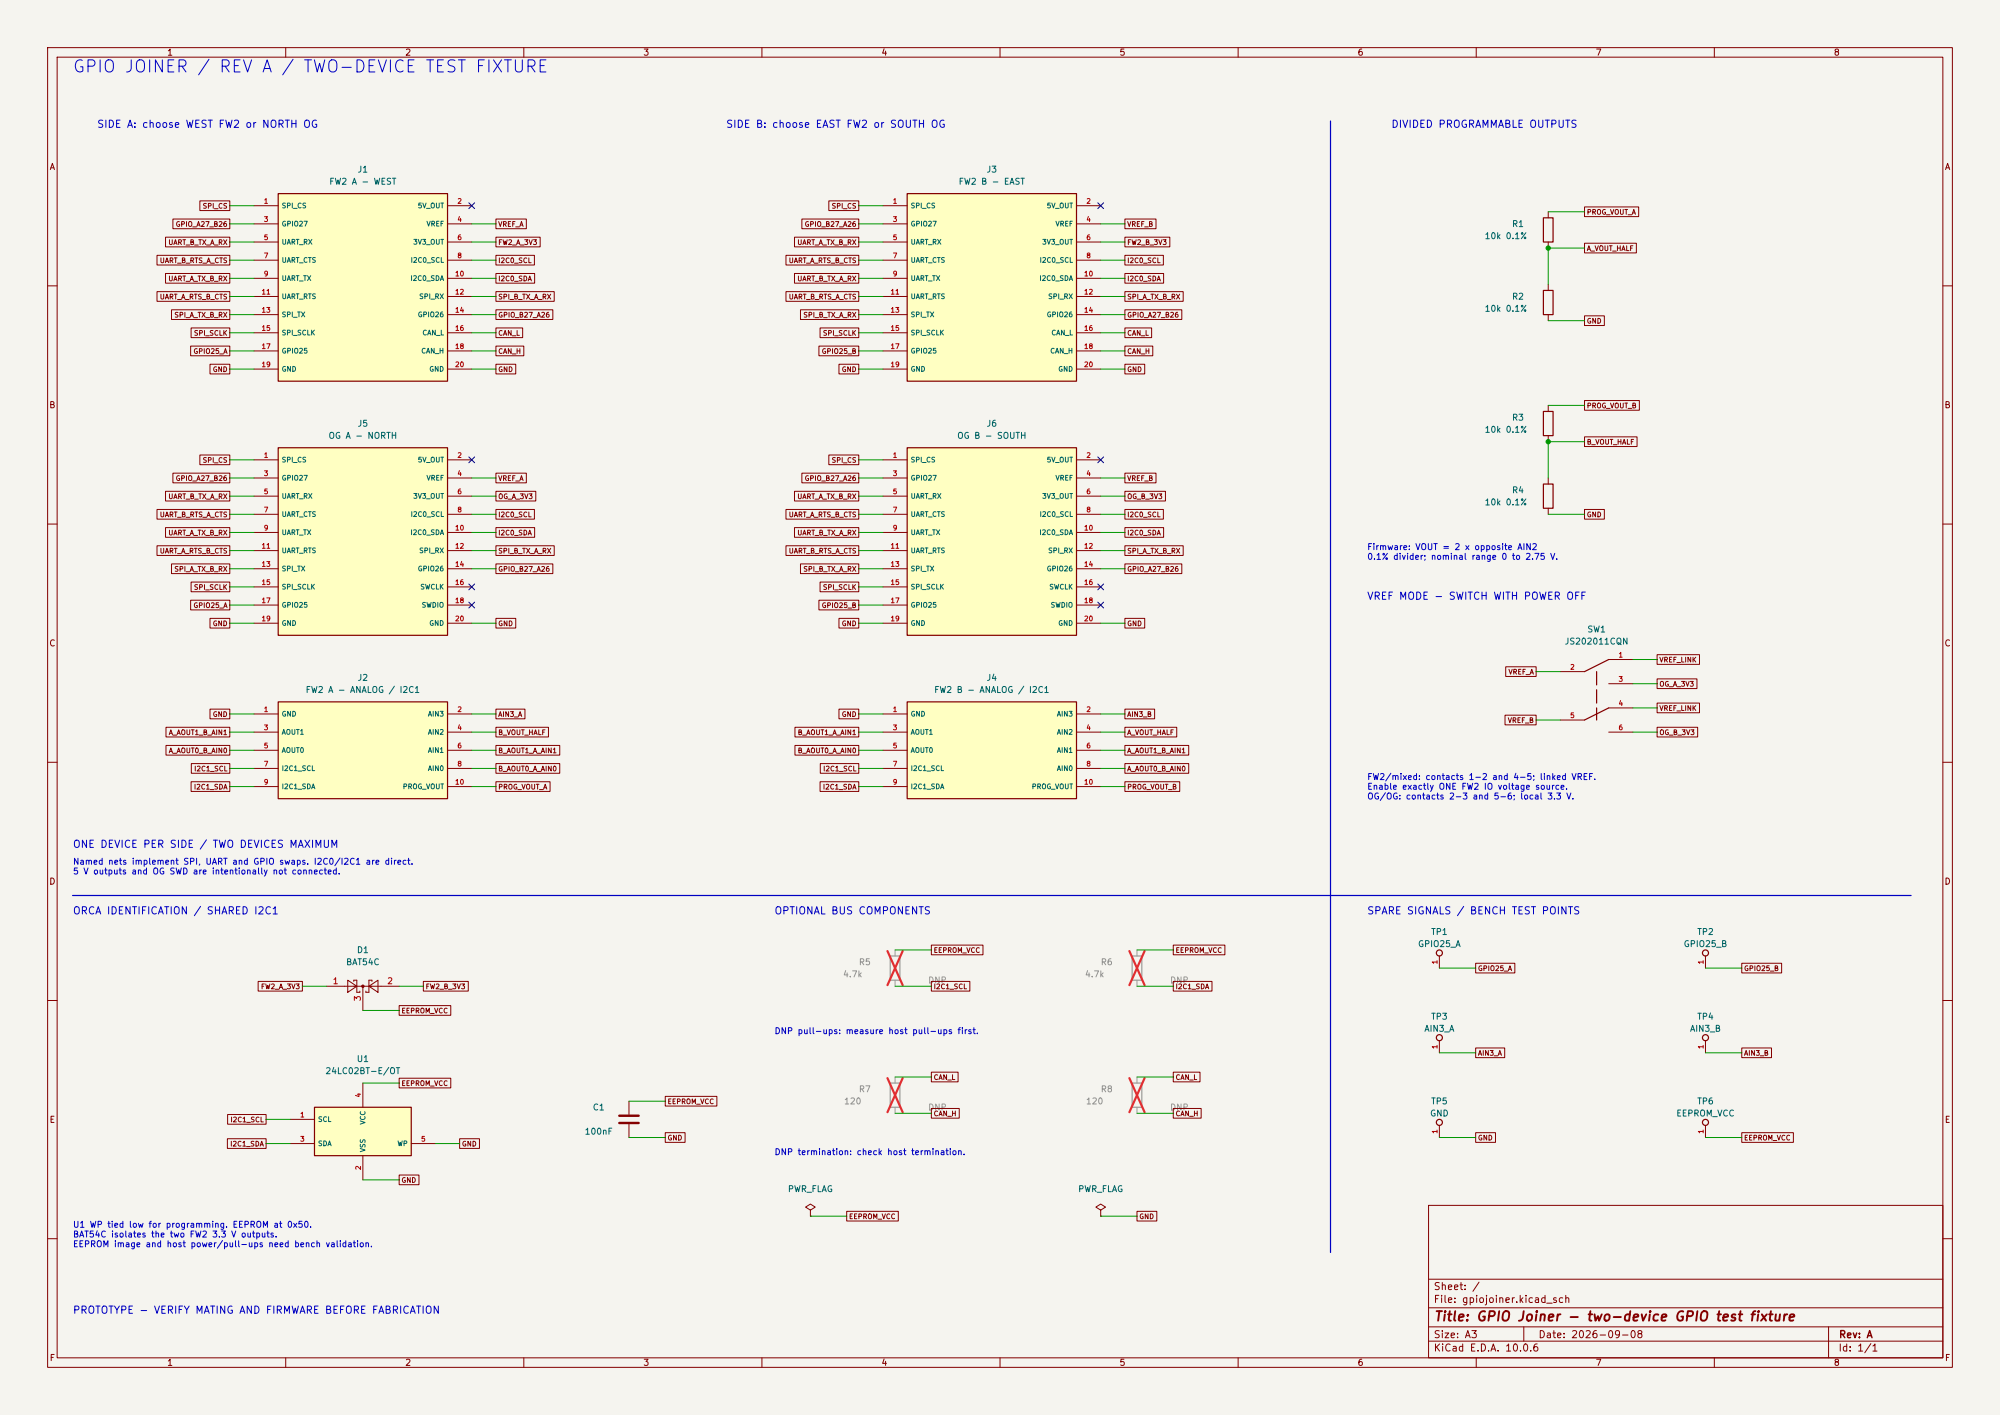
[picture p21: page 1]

GPIO JOINER / REV A / TWO-DEVICE TEST FIXTURE

SIDE A: choose WEST FW2 or NORTH OG

SIDE B: choose EAST FW2 or SOUTH OG

Firmware: VOUT = 2 x opposite AIN2
0.1% divider; nominal range 0 to 2.75 V. FW2/mixed: contacts 1-2 and 4-5; linked VREF. Enable exactly ONE FW2 IO voltage source. OG/OG: contacts 2-3 and 5-6; local 3.3 V.

VREF MODE - SWITCH WITH POWER OFF

ONE DEVICE PER SIDE / TWO DEVICES MAXIMUM

Named nets implement SPI, UART and GPIO swaps. I2C0/I2C1 are direct. 5 V outputs and OG SWD are intentionally not connected. PROTOTYPE - VERIFY MATING AND FIRMWARE BEFORE FABRICATION

DNP pull-ups: measure host pull-ups first. OPTIONAL BUS COMPONENTS

SPARE SIGNALS / BENCH TEST POINTS

DNP termination: check host termination.

U1 WP tied low for programming. EEPROM at 0x50. BAT54C isolates the two FW2 3.3 V outputs. EEPROM image and host power/pull-ups need bench validation.

Sheet: /
File: gpiojoiner.kicad_sch
Title: GPIO Joiner - two-device GPIO test fixture

Size: A3 | Rev: A | F Date: 2026-09-08
KiCad E.D.A. 10.0.6 | Id: 1/1

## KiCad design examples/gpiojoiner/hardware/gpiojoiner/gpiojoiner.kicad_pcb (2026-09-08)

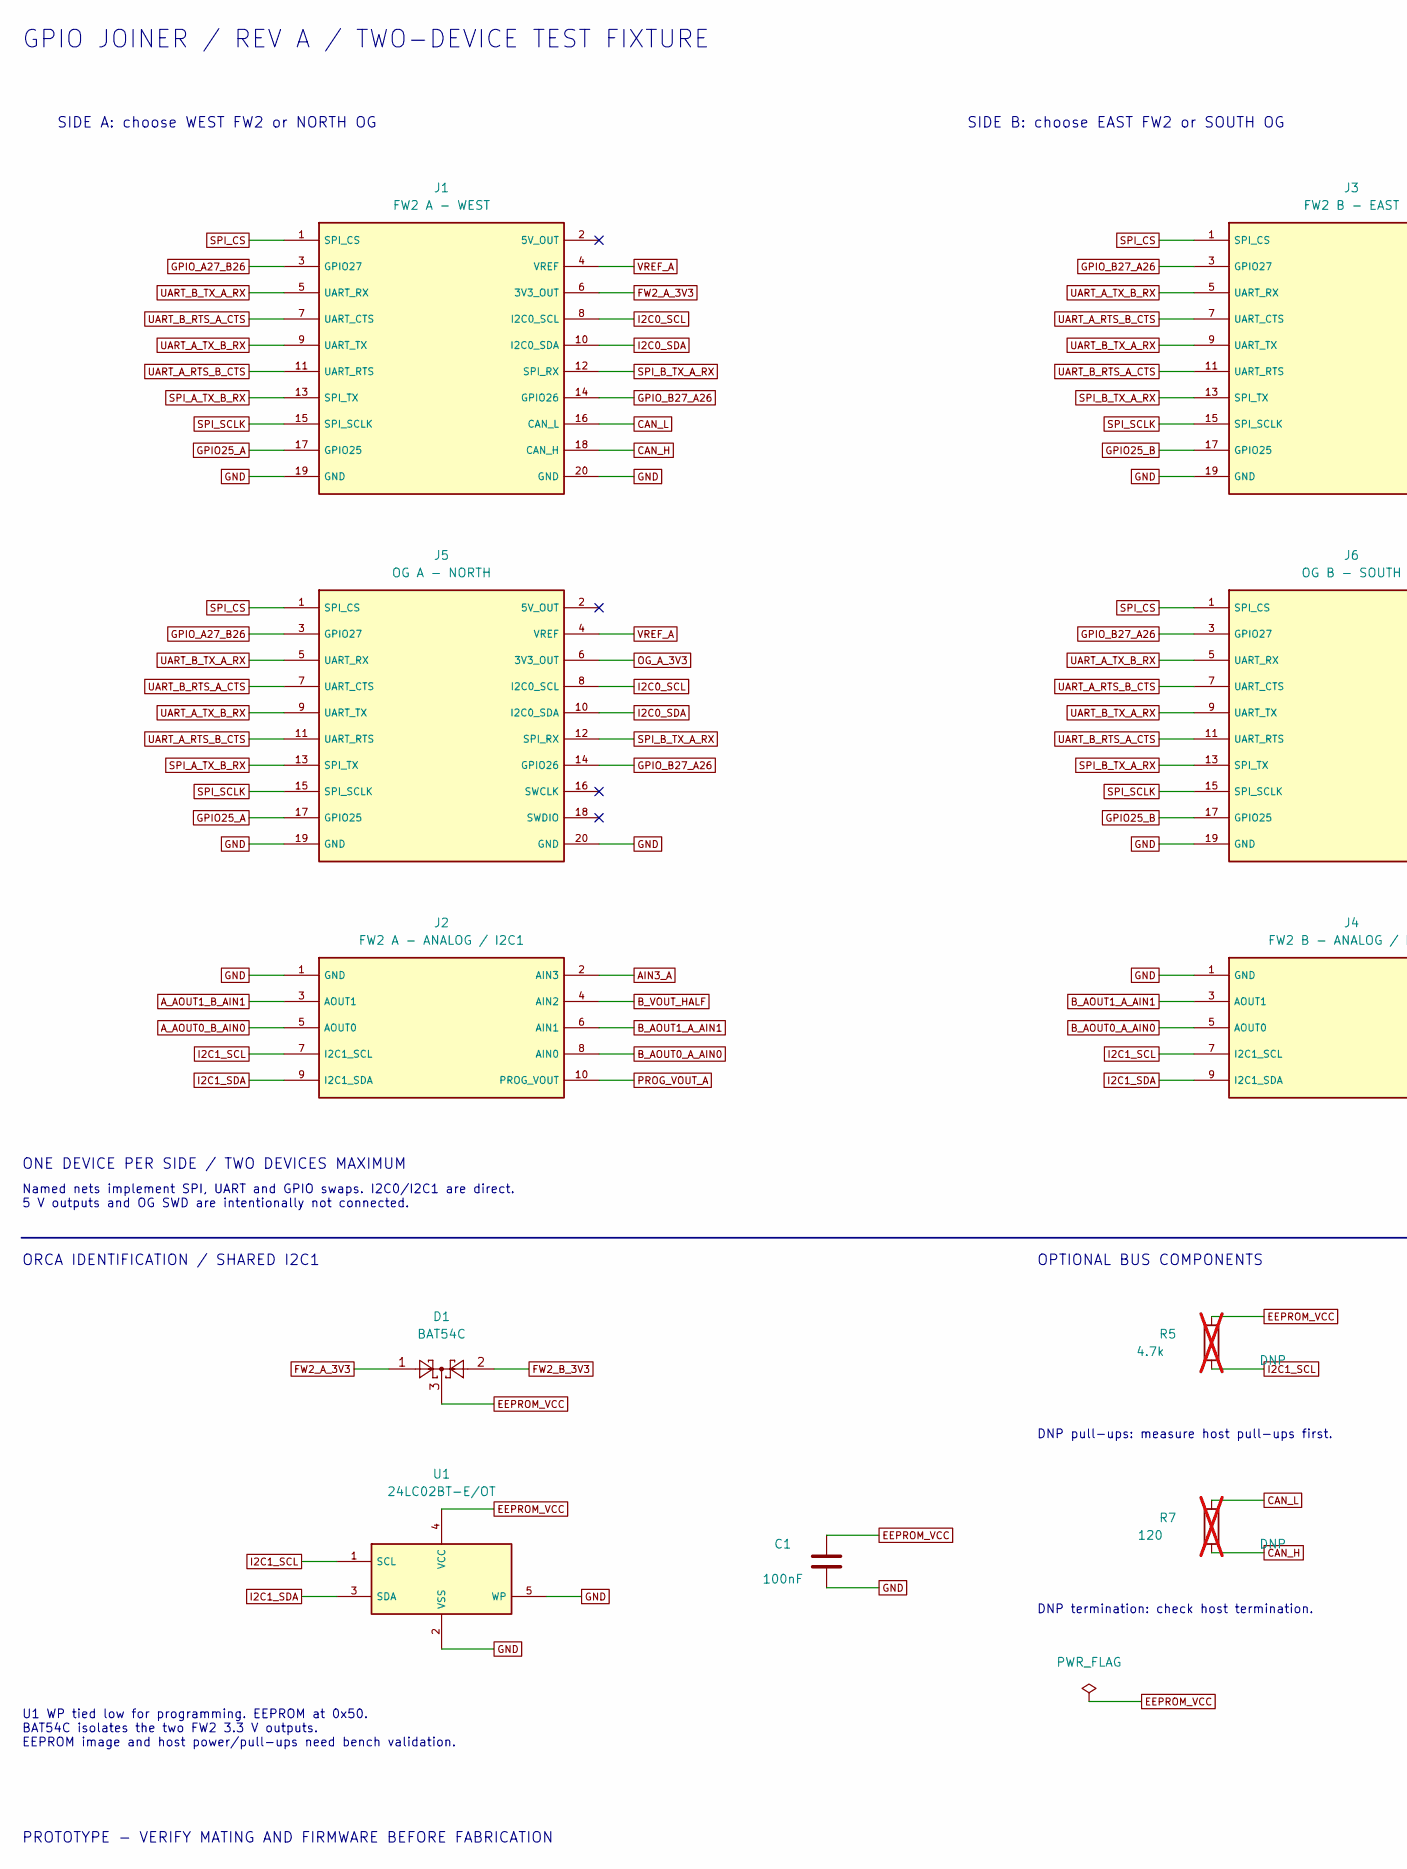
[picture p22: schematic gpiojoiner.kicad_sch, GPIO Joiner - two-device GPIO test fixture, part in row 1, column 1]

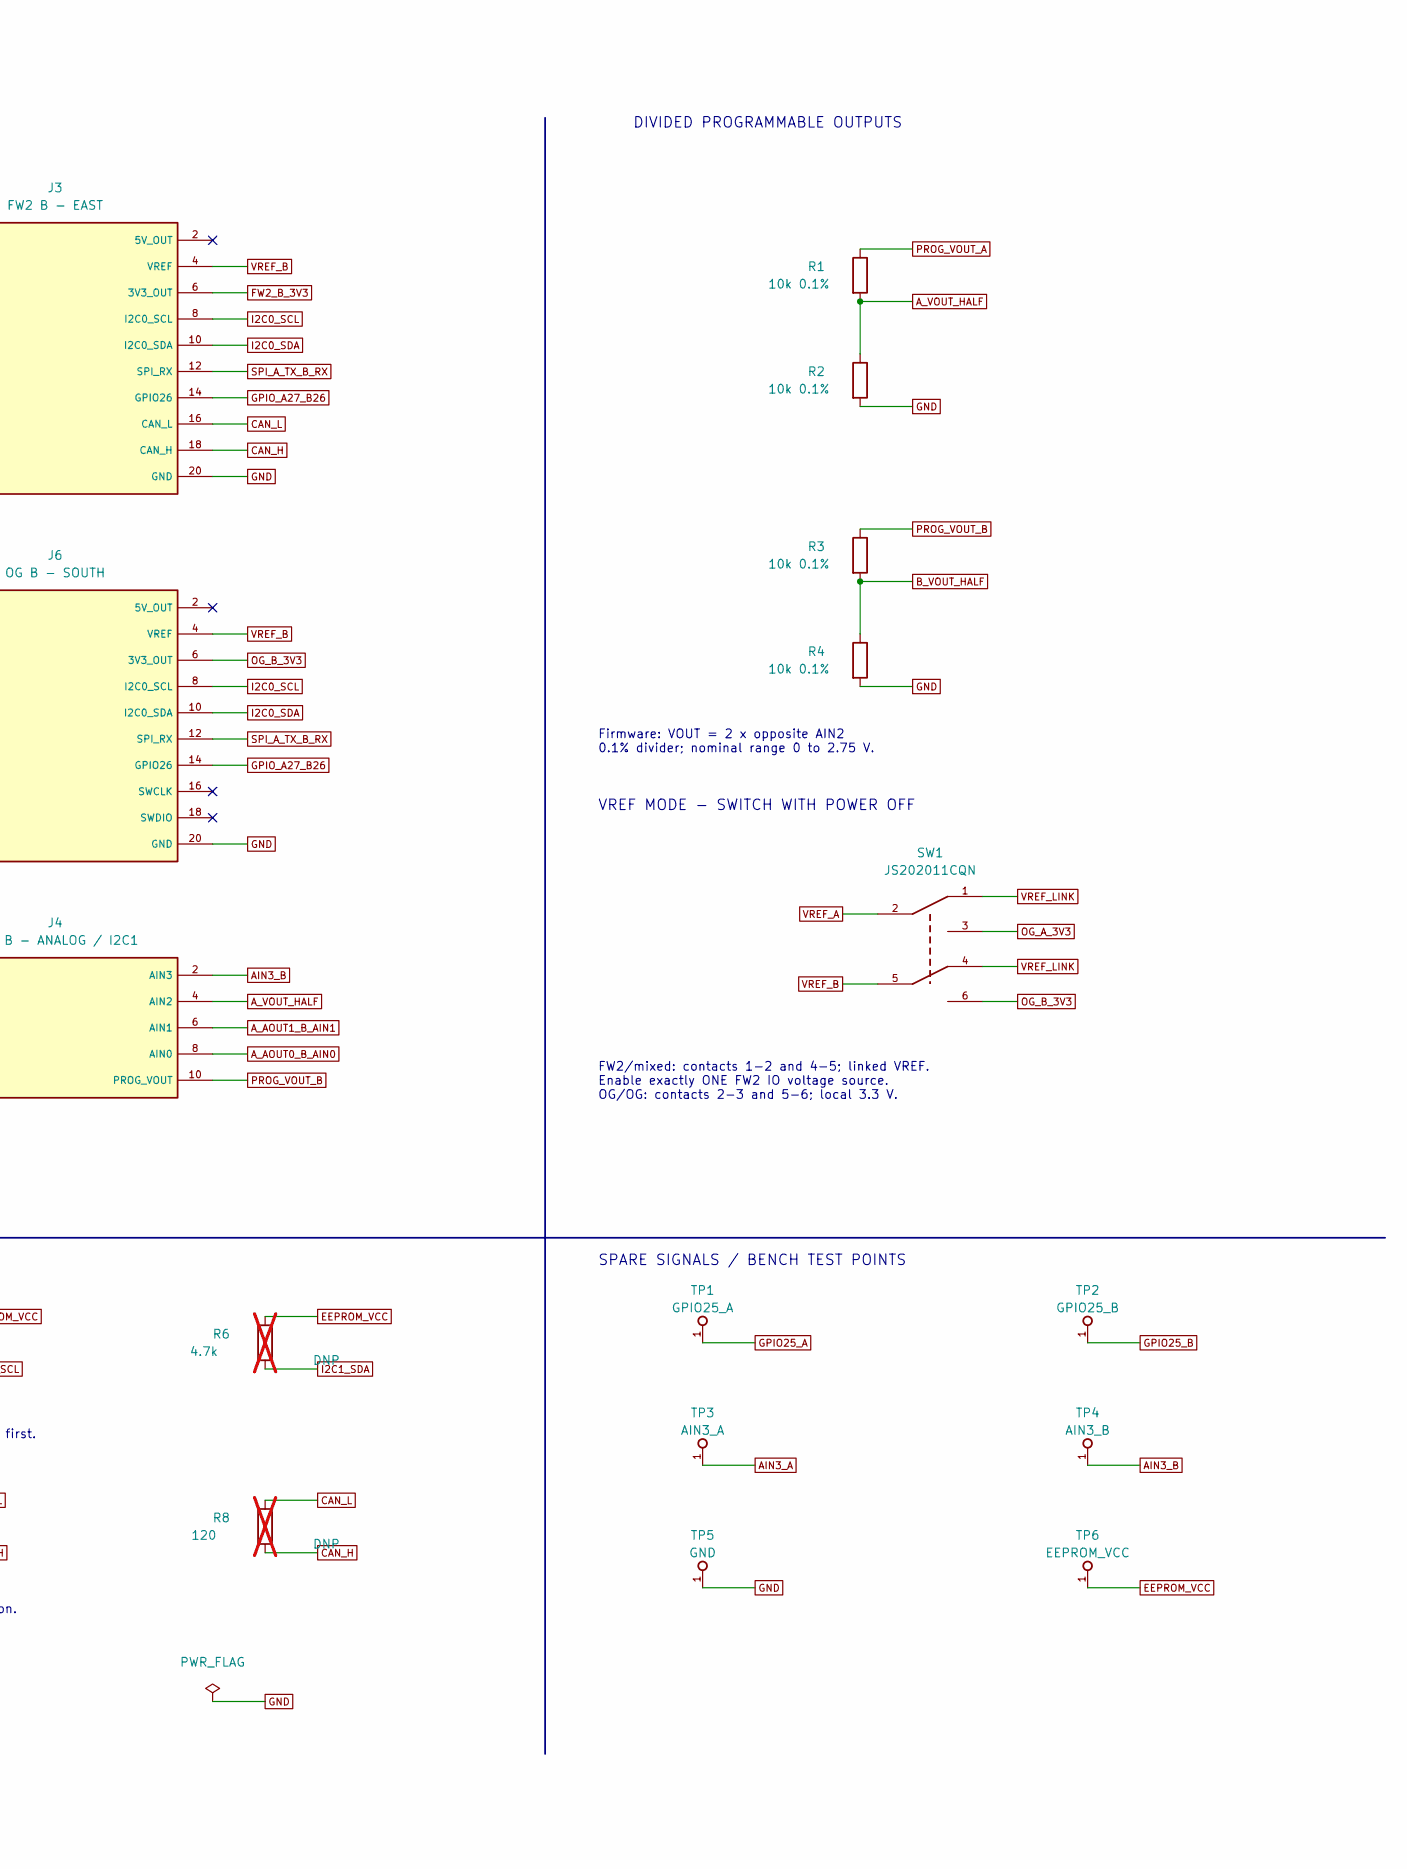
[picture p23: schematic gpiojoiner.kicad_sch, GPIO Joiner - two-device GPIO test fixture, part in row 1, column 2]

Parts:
C1: 100nF; C_0603_1608Metric
D1: BAT54C; SOT-23
J1: FW2 A - WEST; ORCA_20_RA
J2: FW2 A - ANALOG / I2C1; ORCA_10_RA
J3: FW2 B - EAST; ORCA_20_RA
J4: FW2 B - ANALOG / I2C1; ORCA_10_RA
J5: OG A - NORTH; ORCA_20_RA
J6: OG B - SOUTH; ORCA_20_RA
R1, R2, R3, R4: 10k 0.1%; R_0603_1608Metric
R5, R6: 4.7k; R_0603_1608Metric; not fitted
R7, R8: 120; R_0603_1608Metric; not fitted
SW1: JS202011CQN; SW_JS202011CQN
TP1: GPIO25_A; TestPoint_Pad_D1.5mm
TP2: GPIO25_B; TestPoint_Pad_D1.5mm
TP3: AIN3_A; TestPoint_Pad_D1.5mm
TP4: AIN3_B; TestPoint_Pad_D1.5mm
TP5: GND; TestPoint_Pad_D1.5mm
TP6: EEPROM_VCC; TestPoint_Pad_D1.5mm
U1: 24LC02BT-E/OT; SOT-23-5

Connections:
AIN3_A: J2.2 (AIN3), TP3.1
AIN3_B: J4.2 (AIN3), TP4.1
A_AOUT0_B_AIN0: J2.5 (AOUT0), J4.8 (AIN0)
A_AOUT1_B_AIN1: J2.3 (AOUT1), J4.6 (AIN1)
A_VOUT_HALF: J4.4 (AIN2), R1.2, R2.1
B_AOUT0_A_AIN0: J2.8 (AIN0), J4.5 (AOUT0)
B_AOUT1_A_AIN1: J2.6 (AIN1), J4.3 (AOUT1)
B_VOUT_HALF: J2.4 (AIN2), R3.2, R4.1
CAN_H: J1.18 (CAN_H), J3.18 (CAN_H), R7.2, R8.2
CAN_L: J1.16 (CAN_L), J3.16 (CAN_L), R7.1, R8.1
EEPROM_VCC: C1.1, D1.3, R5.1, R6.1, TP6.1, U1.4 (VCC)
FW2_A_3V3: D1.1, J1.6 (3V3_OUT)
FW2_B_3V3: D1.2, J3.6 (3V3_OUT)
GND: C1.2, J1.19 (GND), J1.20 (GND), J2.1 (GND), J3.19 (GND), J3.20 (GND), J4.1 (GND), J5.19 (GND), J5.20 (GND), J6.19 (GND), J6.20 (GND), R2.2, R4.2, TP5.1, U1.2 (VSS), U1.5 (WP)
GPIO25_A: J1.17 (GPIO25), J5.17 (GPIO25), TP1.1
GPIO25_B: J3.17 (GPIO25), J6.17 (GPIO25), TP2.1
GPIO_A27_B26: J1.3 (GPIO27), J3.14 (GPIO26), J5.3 (GPIO27), J6.14 (GPIO26)
GPIO_B27_A26: J1.14 (GPIO26), J3.3 (GPIO27), J5.14 (GPIO26), J6.3 (GPIO27)
I2C0_SCL: J1.8 (I2C0_SCL), J3.8 (I2C0_SCL), J5.8 (I2C0_SCL), J6.8 (I2C0_SCL)
I2C0_SDA: J1.10 (I2C0_SDA), J3.10 (I2C0_SDA), J5.10 (I2C0_SDA), J6.10 (I2C0_SDA)
I2C1_SCL: J2.7 (I2C1_SCL), J4.7 (I2C1_SCL), R5.2, U1.1 (SCL)
I2C1_SDA: J2.9 (I2C1_SDA), J4.9 (I2C1_SDA), R6.2, U1.3 (SDA)
OG_A_3V3: J5.6 (3V3_OUT), SW1.3
OG_B_3V3: J6.6 (3V3_OUT), SW1.6
PROG_VOUT_A: J2.10 (PROG_VOUT), R1.1
PROG_VOUT_B: J4.10 (PROG_VOUT), R3.1
SPI_A_TX_B_RX: J1.13 (SPI_TX), J3.12 (SPI_RX), J5.13 (SPI_TX), J6.12 (SPI_RX)
SPI_B_TX_A_RX: J1.12 (SPI_RX), J3.13 (SPI_TX), J5.12 (SPI_RX), J6.13 (SPI_TX)
SPI_CS: J1.1 (SPI_CS), J3.1 (SPI_CS), J5.1 (SPI_CS), J6.1 (SPI_CS)
SPI_SCLK: J1.15 (SPI_SCLK), J3.15 (SPI_SCLK), J5.15 (SPI_SCLK), J6.15 (SPI_SCLK)
UART_A_RTS_B_CTS: J1.11 (UART_RTS), J3.7 (UART_CTS), J5.11 (UART_RTS), J6.7 (UART_CTS)
UART_A_TX_B_RX: J1.9 (UART_TX), J3.5 (UART_RX), J5.9 (UART_TX), J6.5 (UART_RX)
UART_B_RTS_A_CTS: J1.7 (UART_CTS), J3.11 (UART_RTS), J5.7 (UART_CTS), J6.11 (UART_RTS)
UART_B_TX_A_RX: J1.5 (UART_RX), J3.9 (UART_TX), J5.5 (UART_RX), J6.9 (UART_TX)
VREF_A: J1.4 (VREF), J5.4 (VREF), SW1.2
VREF_B: J3.4 (VREF), J6.4 (VREF), SW1.5
VREF_LINK: SW1.1, SW1.4

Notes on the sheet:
GPIO JOINER / REV A / TWO-DEVICE TEST FIXTURE
SIDE A: choose WEST FW2 or NORTH OG
SIDE B: choose EAST FW2 or SOUTH OG
DIVIDED PROGRAMMABLE OUTPUTS
Firmware: VOUT = 2 x opposite AIN2 0.1% divider; nominal range 0 to 2.75 V.
ONE DEVICE PER SIDE / TWO DEVICES MAXIMUM
Named nets implement SPI, UART and GPIO swaps. I2C0/I2C1 are direct. 5 V outputs and OG SWD are intentionally not connected.
ORCA IDENTIFICATION / SHARED I2C1
OPTIONAL BUS COMPONENTS
DNP pull-ups: measure host pull-ups first.
DNP termination: check host termination.
VREF MODE - SWITCH WITH POWER OFF
FW2/mixed: contacts 1-2 and 4-5; linked VREF. Enable exactly ONE FW2 IO voltage source. OG/OG: contacts 2-3 and 5-6; local 3.3 V.
SPARE SIGNALS / BENCH TEST POINTS
U1 WP tied low for programming. EEPROM at 0x50. BAT54C isolates the two FW2 3.3 V outputs. EEPROM image and host power/pull-ups need bench validation.
PROTOTYPE - VERIFY MATING AND FIRMWARE BEFORE FABRICATION

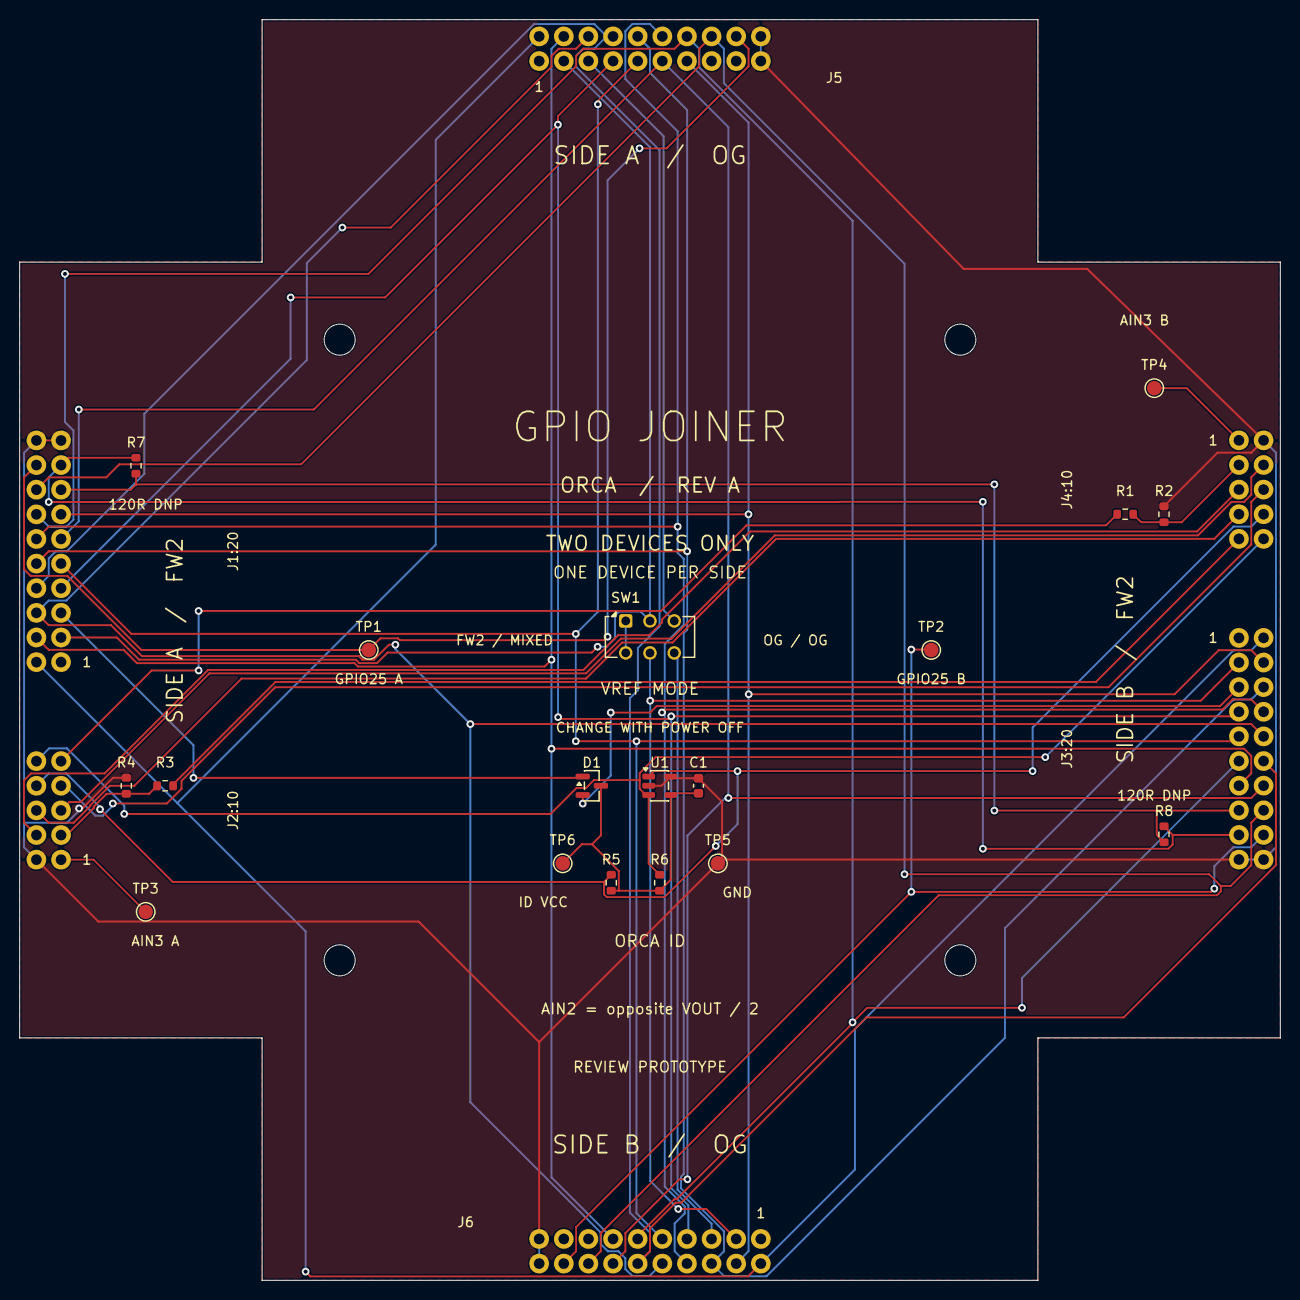
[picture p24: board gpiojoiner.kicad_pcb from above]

Board: 2 copper layers, 130.0 x 130.0 mm, 28 parts (0 on the bottom side), 37 nets.

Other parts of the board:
H1, H2, H3, H4: MountingHole_3.2mm_M3

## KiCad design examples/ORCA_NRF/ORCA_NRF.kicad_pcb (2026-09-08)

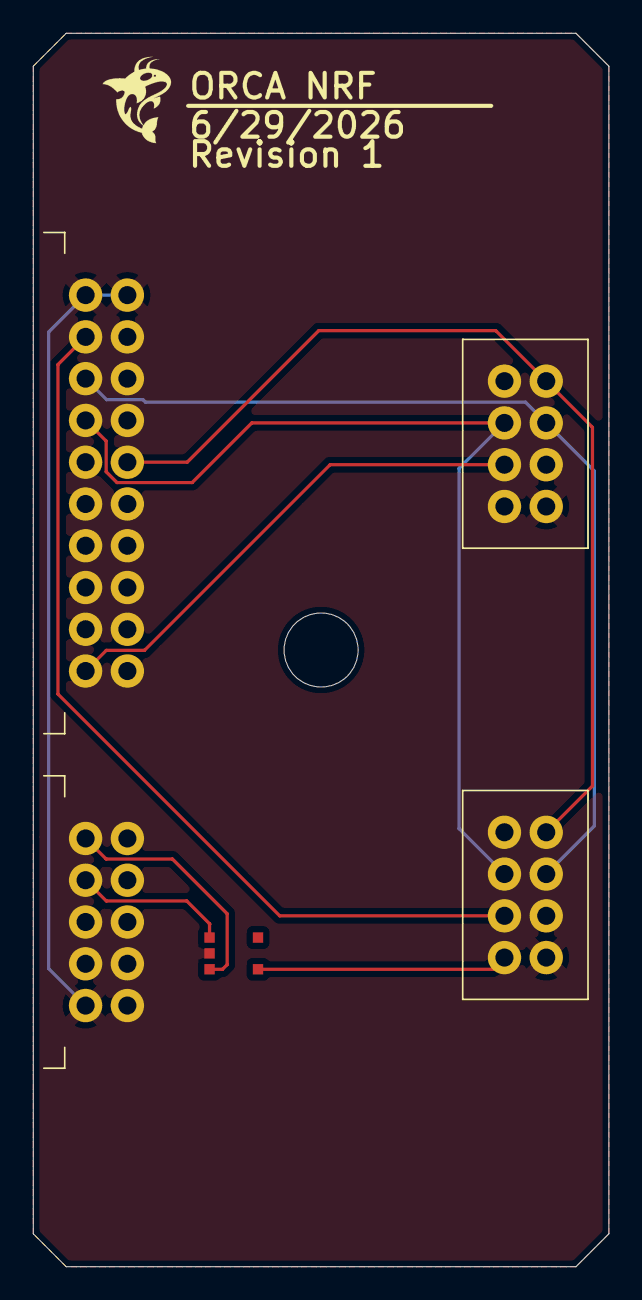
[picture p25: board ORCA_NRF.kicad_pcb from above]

Board: 2 copper layers, 35.0 x 75.0 mm, 5 parts (0 on the bottom side), 9 nets.

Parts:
CN1: IDC_20_Print
CN2: IDC_10_Print
CN3, CN4: NRF_F_CN
EEPROM1: 24LC02BT-E_OT

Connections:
3V3: CN1.6 (3V3), CN3.2 (VCC), CN4.2 (VCC), EEPROM1.4 (VCC)
GND: CN1.19 (GND), CN1.20 (GND), CN2.1 (GND), CN3.1 (GND), CN4.1 (GND), EEPROM1.2 (VSS)
unnamed: CN1.17 (GPIO25), CN4.4 (CSN)
unnamed: CN1.12 (SPI1_Rx), CN3.7 (MISO), CN4.7 (MISO)
unnamed: CN1.15 (SPI1_SCLK), CN3.5 (SCK), CN4.5 (SCK)
unnamed: CN1.13 (SPI1_Tx), CN3.6 (MOSI), CN4.6 (MOSI)
unnamed: CN1.1 (SPI_CS), CN3.4 (CSN)
unnamed: CN2.7 (SCLM1), EEPROM1.1 (SCL)
unnamed: CN2.9 (SDAM1), EEPROM1.3 (SDA)

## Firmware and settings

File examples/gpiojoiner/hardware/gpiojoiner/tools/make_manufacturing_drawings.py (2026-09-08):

"""Create a dimensioned fit check and assembly reference PDF from exported CAD.

Run with Python containing reportlab. Dimensions are mm; page 1 is exactly 1:1.
"""
from pathlib import Path
import json
from reportlab.pdfgen import canvas
from reportlab.lib.pagesizes import letter
from reportlab.lib.units import mm
from reportlab.lib.colors import HexColor, black, white
from reportlab.platypus import Paragraph
from reportlab.lib.styles import ParagraphStyle

ROOT=Path(__file__).resolve().parents[1]
OUT=ROOT/'manufacturing/revA'
G=json.loads((OUT/'checks/geometry.json').read_text())
PARTS=json.loads((ROOT/'manufacturing/parts.json').read_text())
FPS={f['ref']:f for f in G['footprints']}
BLUE=HexColor('#204A67');GRAY=HexColor('#64717E');RED=HexColor('#A83438')
STYLE=ParagraphStyle('body',fontName='Helvetica',fontSize=9,leading=12,textColor=black)


def para(c,text,x,y,width):
    p=Paragraph(text,STYLE);_,h=p.wrap(width,500);p.drawOn(c,x,y-h);return y-h


def heading(c,title,subtitle,page):
    c.setFillColor(BLUE);c.setFont('Helvetica-Bold',17);c.drawString(15*mm,263*mm,title)
    c.setFillColor(GRAY);c.setFont('Helvetica',9);c.drawString(15*mm,255*mm,subtitle)
    c.setStrokeColor(BLUE);c.setLineWidth(.7);c.line(15*mm,251*mm,201*mm,251*mm)
    c.setFont('Helvetica',8);c.drawString(15*mm,8*mm,'GPIO Joiner rev A | Prototype quotation / engineering review | 2026-09-08')
    c.drawRightString(201*mm,8*mm,f'{page} / 3')


def board(c,base=(43,82),scale=1,allparts=False):
    def xy(p):return ((base[0]+(p[0]-85)*scale)*mm,(base[1]+(215-p[1])*scale)*mm)
    c.setStrokeColor(black);c.setLineWidth(.15*mm)
    for a,b in G['outline']:c.line(*xy(a),*xy(b))
    for fp in G['footprints']:
        ref=fp['ref']
        if not allparts and not ref.startswith(('J','H')):continue
        for p in fp['pads']:
            x,y=xy(p['xy']);w,h=p['size'];dr=p['drill'][0]
            c.setStrokeColor(RED if fp['dnp'] else GRAY);c.setFillColor(white)
            if dr:
                c.circle(x,y,dr*mm*scale/2,stroke=1,fill=0)
                if ref.startswith('J'):c.circle(x,y,min(w,h)*mm*scale/2,stroke=1,fill=0)
            else:c.rect(x-w*mm*scale/2,y-h*mm*scale/2,w*mm*scale,h*mm*scale,stroke=1,fill=0)
            if p['number']=='1' and ref.startswith('J'):
                c.setFillColor(BLUE);c.setFont('Helvetica-Bold',7)
                dx,dy={'J1':(4,0),'J2':(4,0),'J3':(-5,0),'J4':(-5,0),'J5':(0,-4),'J6':(0,3)}[ref]
                c.drawString(x+dx*mm*scale,y+dy*mm*scale,'1')
        x,y=xy(fp['xy']);c.setFont('Helvetica-Bold',8);c.setFillColor(BLUE)
        if ref.startswith('J'):
            dx,dy={'J1':(12,0),'J2':(12,0),'J3':(-18,0),'J4':(-18,0),'J5':(0,-12),'J6':(0,12)}[ref]
            if allparts and ref=='J4':dx=-36
            c.drawString(x+dx*mm*scale,y+dy*mm*scale,f'{ref} / {len(fp["pads"])} pin')
        elif ref.startswith('H'):c.drawString(x+3*mm,y+3*mm,ref)
        elif allparts:
            callouts={'R1':(194,141),'R2':(206,145),'R3':(104,160),'R4':(93,160),
                      'D1':(141,159),'U1':(150,157),'C1':(160,160),
                      'R5':(138,178),'R6':(155,180),'TP6':(137,169),'TP5':(161,169)}
            if ref in callouts:
                tx,ty=xy(callouts[ref]);c.setStrokeColor(GRAY);c.setLineWidth(.3)
                c.line(x,y,tx,ty+(3.8 if ty<y else -1)*mm)
            else:tx,ty=x,y+2.7*mm
            c.setFillColor(RED if fp['dnp'] else BLUE)
            c.drawCentredString(tx,ty,ref+(' DNP' if fp['dnp'] else ''))
    return xy


def detail(c,ref,cx,cy,scale,netnames):
    fp=FPS[ref];mx=sum(p['xy'][0] for p in fp['pads'])/len(fp['pads']);my=sum(p['xy'][1] for p in fp['pads'])/len(fp['pads'])
    c.setFillColor(BLUE);c.setFont('Helvetica-Bold',12);c.drawCentredString(cx*mm,(cy+18)*mm,ref+' - TOP VIEW')
    for p in fp['pads']:
        x=(cx+(p['xy'][0]-mx)*scale)*mm;y=(cy-(p['xy'][1]-my)*scale)*mm
        w,h=p['size'];c.setStrokeColor(GRAY);c.setFillColor(HexColor('#E8EDF1'))
        c.rect(x-w*mm*scale/2,y-h*mm*scale/2,w*mm*scale,h*mm*scale,stroke=1,fill=1)
        c.setFillColor(black);c.setFont('Helvetica-Bold',9);c.drawCentredString(x,y-3,p['number'])
        if ref!='SW1':
            label=netnames[p['number']];c.setFont('Helvetica',8)
            if p['xy'][0]<mx:c.drawRightString(x-w*mm*scale/2-3,y-3,label)
            else:c.drawString(x+w*mm*scale/2+3,y-3,label)


def make():
    target=OUT/'drawings/gpiojoiner-revA-manufacturing.pdf'
    c=canvas.Canvas(str(target),pagesize=letter);c.setTitle('GPIO Joiner rev A - manufacturing and fit reference')
    heading(c,'Mechanical fit check - print at 100%','US Letter. Actual size / 1:1. Disable Fit to page. All dimensions in mm.',1)
    xy=board(c)
    c.setStrokeColor(BLUE);c.setFillColor(BLUE);c.setLineWidth(.4)
    c.line(43*mm,224*mm,173*mm,224*mm)
    for x in [43,173]:c.line(x*mm,221*mm,x*mm,227*mm)
    c.setFont('Helvetica-Bold',10);c.drawCentredString(108*mm,226*mm,'130.00')
    c.line(30*mm,82*mm,30*mm,212*mm)
    for y in [82,212]:c.line(27*mm,y*mm,33*mm,y*mm)
    c.saveState();c.translate(27*mm,147*mm);c.rotate(90);c.drawCentredString(0,0,'130.00');c.restoreState()
    for label,p in [('OG A / SIDE A',[150,109]),('FW2 A',[105,157]),('FW2 B',[195,148]),('OG B / SIDE B',[150,191])]:
        c.setFont('Helvetica-Bold',8);c.drawCentredString(*xy(p),label)
    para(c,'FW2 connector centers: <b>26.72 mm</b>. Pitch and row spacing: <b>2.54 mm</b>. Connector drill: <b>1.10 mm</b>. Four support holes: <b>3.20 mm NPTH</b>.',15*mm,68*mm,119*mm)
    para(c,'Compare this hole pattern with real FW2 and OG devices, using the actual keyed connectors. Verify pin 1, mating direction, enclosure clearance, and board thickness. Full device enclosures have not been validated.',15*mm,46*mm,119*mm)
    c.setStrokeColor(black);c.setFillColor(black);c.rect(146*mm,15*mm,50*mm,50*mm,fill=0)
    c.setFont('Helvetica-Bold',9);c.drawCentredString(171*mm,40*mm,'50 x 50 mm')
    c.setFont('Helvetica',8);c.drawCentredString(171*mm,35*mm,'Check BOTH axes')
    c.showPage()
    heading(c,'Assembly placement reference','Top view. All 14 fitted components on top. R5-R8 are DO NOT POPULATE.',2)
    board(c,base=(43,106),allparts=True)
    y=91*mm
    for refs,text in [
        ('J1 J3 J5 J6','Sullins SFH11-PBPC-D10-RA-BK (20 positions)'),
        ('J2 J4','Sullins SFH11-PBPC-D05-RA-BK (10 positions)'),
        ('SW1','C&K JS202011CQN - contact-state check required'),
        ('U1 / D1','24LC02BT-E/OT / BAT54C,215 - orientation on page 3'),
        ('C1 / R1-R4','100 nF X7R 50 V / 10 kohm 0.1%, 0603'),
        ('R5-R8','DNP: no components and no stencil apertures'),
        ('TP1-TP6 / H1-H4','Copper test pads / mounting holes; no purchased parts')]:
        c.setFillColor(BLUE);c.setFont('Helvetica-Bold',9);c.drawString(15*mm,y,refs)
        c.setFillColor(black);c.setFont('Helvetica',9);c.drawString(55*mm,y,text);y-=7*mm
    para(c,'Install the small SMD parts before the through-hole connectors. Connectors mate outward and overhang the board. Let the assembler add tooling rails/fiducials and choose a fixture or hand-solder operation; confirm the panel drawing before production.',15*mm,35*mm,186*mm)
    c.showPage()
    heading(c,'Assembly details and fabrication notes','Pin numbers below are PCB pad numbers. Check package markings and supplier placement preview.',3)
    detail(c,'U1',60,218,5,{'1':'SCL','2':'GND','3':'SDA','4':'VCC','5':'WP / GND'})
    detail(c,'D1',153,218,5,{'1':'FW2 A 3V3','2':'FW2 B 3V3','3':'EEPROM VCC'})
    detail(c,'SW1',62,163,4,{})
    para(c,'<b>VREF slide switch</b><br/>Left: pads 1-2 and 4-5 connected (FW2 / MIXED).<br/>Right: pads 2-3 and 5-6 connected (OG / OG).<br/>Verify with a meter on the actual part before fitting the batch. Never switch with devices powered.',109*mm,180*mm,88*mm)
    y=133*mm
    notes=[
        '<b>Prototype quote:</b> five boards as a working quantity. FR-4, two layers, 1.60 mm finished thickness, 1 oz finished copper, green solder mask, white legend both sides, lead-free ENIG finish.',
        '<b>Outline and holes:</b> CNC-route the cross. 130 x 130 mm bounding box. No V-score or castellations. Finished holes: 158 plated, 4 non-plated. Allow normal inside router corner radii up to 1 mm. Electrical test required.',
        '<b>Assembly:</b> seven SMD parts and seven through-hole parts per board. Four resistor positions are DNP. Do not substitute connectors, switch, EEPROM package, or diode configuration without review. Keep 0.1% divider resistors.',
        '<b>Coordinates:</b> Gerber/drill/CPL origin is lower left of the board bounding box. X right, Y up, mm. CPL uses native KiCad footprint origins/rotations. Through-hole origins are placement datums, not necessarily plastic-body centers. Align vendor models using the actual hole/pad pattern and this drawing.',
        '<b>EEPROM:</b> fit U1 blank. No programming image or factory functional test is supplied. During bring-up, use one I2C1 controller, verified 3.3 V pull-ups and at most 400 kHz. A programmed ORCA ID remains a separate task.',
        '<b>Use:</b> one device per side, two total. Set VREF mode with power off. Programmable-output measurement is 2 x the opposite AIN2 value. Physical fit and bench operation remain unverified.'
    ]
    for note in notes:y=para(c,note,15*mm,y,186*mm)-4*mm
    assert y>16*mm, 'Notes overflow page'
    c.save();print('Created',target)


if __name__=='__main__':make()

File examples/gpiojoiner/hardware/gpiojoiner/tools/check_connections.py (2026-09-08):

"""Independent acceptance audit of KiCad XML, based on DESIGN.md and PINOUTS.md.

No imports from the generator: this checks the actual exported CAD connectivity.
"""
from pathlib import Path
import sys
import xml.etree.ElementTree as ET

ROOT = Path(__file__).resolve().parents[1]

def audit(path):
    if not path.is_file():
        raise AssertionError(f"Missing exported KiCad netlist: {path}")
    tree = ET.parse(path)
    parts = {c.attrib['ref']: c for c in tree.findall('./components/comp')}
    expected_refs={f'J{i}' for i in range(1,7)} | {f'R{i}' for i in range(1,9)} | {f'TP{i}' for i in range(1,7)} | {'U1','D1','C1','SW1'}
    assert set(parts)==expected_refs, f"Unexpected/missing physical components: {set(parts)^expected_refs}"
    expected_footprints={
        'U1':'Package_TO_SOT_SMD:SOT-23-5',
        'D1':'Package_TO_SOT_SMD:SOT-23',
        'SW1':'GPIOJoiner:SW_JS202011CQN',
        'C1':'Capacitor_SMD:C_0603_1608Metric',
    }
    expected_footprints.update({f'J{i}':'GPIOJoiner:ORCA_10_RA' if i in (2,4) else 'GPIOJoiner:ORCA_20_RA' for i in range(1,7)})
    expected_footprints.update({f'R{i}':'Resistor_SMD:R_0603_1608Metric' for i in range(1,9)})
    expected_footprints.update({f'TP{i}':'TestPoint:TestPoint_Pad_D1.5mm' for i in range(1,7)})
    for ref,footprint in expected_footprints.items():
        assert parts[ref].findtext('footprint') == footprint, f"Wrong footprint {ref}"
    nets = {}
    for n in tree.findall('./nets/net'):
        for p in n.findall('node'):
            key = (p.attrib['ref'], p.attrib['pin'])
            assert key not in nets, f"Duplicate pin {key}"
            nets[key] = n.attrib['code']
    count = 1+len(expected_footprints)
    def pin(ref, num):
        assert (ref,str(num)) in nets, f"Missing {ref}.{num}"
        return nets[(ref,str(num))]
    def same(*pins):
        nonlocal count
        assert len({pin(*p) for p in pins}) == 1, f"Not connected: {pins}"
        count += 1
    def different(*pins):
        nonlocal count
        values = [pin(*p) for p in pins]
        assert len(set(values)) == len(values), f"Unexpected short: {pins}"
        count += 1
    # Four allowed combinations. No physical-star assumption is used.
    mapping = {1:1,3:14,5:9,7:11,8:8,9:5,10:10,11:7,12:13,13:12,14:3,15:15,19:19,20:20}
    for a in ('J1','J5'):
        for b in ('J3','J6'):
            for pa,pb in mapping.items(): same((a,pa),(b,pb))
            different((a,17),(b,17))
    for refs,side,tp in [(('J1','J5'),'A','TP1'),(('J3','J6'),'B','TP2')]:
        for p in (1,3,4,5,7,8,9,10,11,12,13,14,15,17,19,20): same((refs[0],p),(refs[1],p))
        same((refs[0],17),(tp,1))
    # Supply isolation and no copper ties through passive isolation components.
    different(('J1',6),('J3',6),('J5',6),('J6',6),('U1',4),('J1',4),('J3',4),('J1',19))
    for ref in ('J1','J3','J5','J6'):
        k = nets.get((ref,'2'))
        assert k is None or sum(v == k for v in nets.values()) == 1, f"5V output connected: {ref}"
    for ref in ('J5','J6'):
        for p in (16,18):
            k=nets.get((ref,str(p)))
            assert k is None or sum(v == k for v in nets.values()) == 1, f"OG SWD connected: {ref}.{p}"
    same(('J1',16),('J3',16),('R7',1),('R8',1))
    same(('J1',18),('J3',18),('R7',2),('R8',2))
    different(('J1',16),('J1',18),('J1',19))
    # DPDT pin assignment and simulated contact closures in both modes.
    same(('SW1',2),('J1',4),('J5',4))
    same(('SW1',5),('J3',4),('J6',4))
    same(('SW1',1),('SW1',4))
    same(('SW1',3),('J5',6))
    same(('SW1',6),('J6',6))
    for mode,contacts in [('FW2/mixed',((2,1),(5,4))),('OG/OG',((2,3),(5,6)))]:
        parent={v:v for v in nets.values()}
        def root(x):
            while parent[x] != x: x=parent[x]
            return x
        for a,b in contacts: parent[root(pin('SW1',a))]=root(pin('SW1',b))
        eq=lambda a,b: root(pin(*a)) == root(pin(*b))
        assert eq(('J1',4),('J3',4)) == (mode=='FW2/mixed'), f"VREF state {mode}"
        assert eq(('J1',4),('J5',6)) == (mode=='OG/OG'), f"A reference state {mode}"
        assert eq(('J3',4),('J6',6)) == (mode=='OG/OG'), f"B reference state {mode}"
        rails=[('J1',6),('J3',6),('J5',6),('J6',6)]
        assert len({root(pin(*p)) for p in rails}) == 4, f"Supply short in {mode}"
        count+=4
    # I2C1 direct copper, EEPROM package pins, diode orientation and bypass.
    same(('J2',7),('J4',7),('U1',1),('R5',2))
    same(('J2',9),('J4',9),('U1',3),('R6',2))
    same(('J1',6),('D1',1))
    same(('J3',6),('D1',2))
    same(('D1',3),('U1',4),('C1',1),('R5',1),('R6',1),('TP6',1))
    same(('J1',19),('J1',20),('J3',19),('J3',20),('J5',19),('J5',20),('J6',19),('J6',20),('J2',1),('J4',1),('U1',2),('U1',5),('C1',2),('R2',2),('R4',2),('TP5',1))
    for a,b,upper,lower,tp in [('J2','J4','R1','R2','TP3'),('J4','J2','R3','R4','TP4')]:
        same((a,5),(b,8))
        same((a,3),(b,6))
        same((a,10),(upper,1))
        same((upper,2),(lower,1),(b,4))
        different((a,10),(b,4),('J1',19))
        same((a,2),(tp,1))
    different(('J2',2),('J4',2),('J2',3),('J4',3),('J2',5),('J4',5))
    expected={'U1':'24LC02BT-E/OT','D1':'BAT54C','C1':'100nF','SW1':'JS202011CQN'}
    expected.update({f'R{i}':'10k 0.1%' for i in range(1,5)})
    expected.update({'R5':'4.7k','R6':'4.7k','R7':'120','R8':'120'})
    for ref,value in expected.items():
        assert parts[ref].findtext('value') == value, f"Wrong value {ref}"
        dnp = parts[ref].find("property[@name='dnp']") is not None
        assert dnp == (ref in ('R5','R6','R7','R8')), f"Wrong DNP {ref}"
        count+=2
    # Exact copper membership also catches extra unintended branches, not just missing pairs.
    expected_groups = [
        'J1.1 J3.1 J5.1 J6.1', 'J1.3 J5.3 J3.14 J6.14',
        'J1.14 J5.14 J3.3 J6.3', 'J1.5 J5.5 J3.9 J6.9',
        'J1.9 J5.9 J3.5 J6.5', 'J1.7 J5.7 J3.11 J6.11',
        'J1.11 J5.11 J3.7 J6.7', 'J1.8 J3.8 J5.8 J6.8',
        'J1.10 J3.10 J5.10 J6.10', 'J1.12 J5.12 J3.13 J6.13',
        'J1.13 J5.13 J3.12 J6.12', 'J1.15 J3.15 J5.15 J6.15',
        'J1.17 J5.17 TP1.1','J3.17 J6.17 TP2.1',
        'J1.4 J5.4 SW1.2','J3.4 J6.4 SW1.5','SW1.1 SW1.4',
        'J1.6 D1.1','J3.6 D1.2','J5.6 SW1.3','J6.6 SW1.6',
        'J1.16 J3.16 R7.1 R8.1','J1.18 J3.18 R7.2 R8.2',
        'J2.7 J4.7 U1.1 R5.2','J2.9 J4.9 U1.3 R6.2',
        'D1.3 U1.4 C1.1 R5.1 R6.1 TP6.1',
        'J2.3 J4.6','J2.5 J4.8','J4.3 J2.6','J4.5 J2.8',
        'J2.10 R1.1','R1.2 R2.1 J4.4','J4.10 R3.1','R3.2 R4.1 J2.4',
        'J2.2 TP3.1','J4.2 TP4.1',
        'J1.19 J1.20 J3.19 J3.20 J5.19 J5.20 J6.19 J6.20 J2.1 J4.1 U1.2 U1.5 C1.2 R2.2 R4.2 TP5.1',
    ]
    for group in expected_groups:
        want={tuple(x.split('.')) for x in group.split()}
        key=pin(*next(iter(want)))
        got={p for p,n in nets.items() if n==key and not p[0].startswith('#')}
        assert got==want, f"Unexpected net membership: wanted {want}; got {got}"
        count+=1
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

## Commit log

2026-08-13 Initial commit: FreeWili 2 ORCA KiCad template
    [ORCATemplate.kicad_pcb, ORCATemplate.kicad_sch, ORCATemplate.step]
2026-08-13 Add ORCA connector pinout diagram
2026-09-08 docs: add Free Wili connector pinouts
    Add PINOUTS.md with the Free Wili OG 20-position, Free Wili 2
    20-position, and Free Wili 2 10-position connector tables plus an
    OG vs Free Wili 2 comparison, with the source connector images.
    Claude-Session: https://claude.ai/code/session_0177QChBsph2WyenYcBhGKfm
2026-09-08 feat: add ORCA_NRF example project
    Add a complete KiCad example of an ORCA module board with an NRF24L01
    radio, built from the ORCATemplate, under examples/ORCA_NRF.
    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
    [ORCA_NRF.kicad_pcb, ORCA_NRF.kicad_sch]
2026-09-08 Add GPIO Joiner KiCad example, ORCA agent workflow and board images
    [C_0603_1608Metric.step, ORCA_10_RA.step, ORCA_20_RA.step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]

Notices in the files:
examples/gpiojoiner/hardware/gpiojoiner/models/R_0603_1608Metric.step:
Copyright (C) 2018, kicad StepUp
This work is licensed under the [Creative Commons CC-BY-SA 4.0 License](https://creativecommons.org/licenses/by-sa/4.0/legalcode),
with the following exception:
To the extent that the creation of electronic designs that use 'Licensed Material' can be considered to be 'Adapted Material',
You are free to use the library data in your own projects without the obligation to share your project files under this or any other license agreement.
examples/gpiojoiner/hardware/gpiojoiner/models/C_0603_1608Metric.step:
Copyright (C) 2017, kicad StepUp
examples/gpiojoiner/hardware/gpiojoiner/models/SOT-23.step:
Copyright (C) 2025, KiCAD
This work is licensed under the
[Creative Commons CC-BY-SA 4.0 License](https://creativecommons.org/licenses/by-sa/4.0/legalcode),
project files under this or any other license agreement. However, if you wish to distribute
